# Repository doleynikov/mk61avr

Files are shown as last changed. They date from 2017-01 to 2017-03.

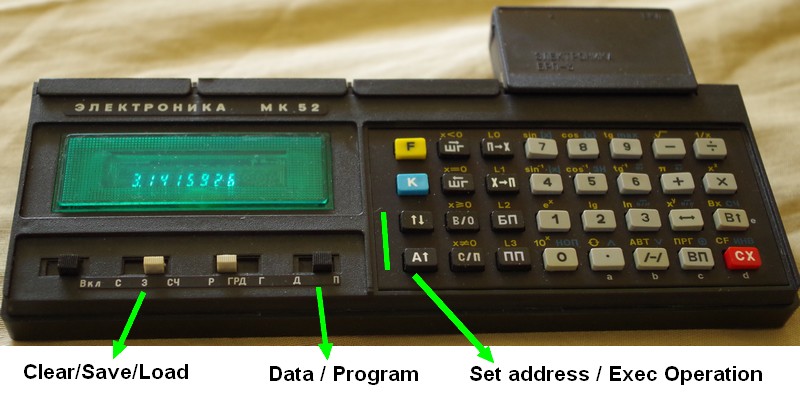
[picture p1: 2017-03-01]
Docs/manual/elek_mk52.jpg

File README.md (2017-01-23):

# mk61avr

**Эмулятор разбросан по файлам**

main.c

mk61types.h

vm61.c

vm61.h

vm61decoder.c

**есть служебные функции**

extlib.c - преобразования 16-ти ричной цифры в символ для печати;

	atoc() - ?;

	чтение-запись участка памяти из/в EEPROM;

**есть работа с аппаратурой**

keyboard.c - работа с клавиатурой как с устройством 

keyboard.h

lcd.c - работа с 16x2 LCD по параллельному интерфейсу

lcd.h

lowlevel.h

micro_os.h

scan_dc.c - преобразование сканкодов клавиатуры в ОПкоды 

store.c - работа с внешним i2c хранилищем

store.h

terminal.c - работа с калькулятором из терминала

terminal.h

time.c - ? работа с таймером. Вероятно для опроса клавиатуры

time.h

twi.c - TWI (i2C) функции для работы с внешним хранилищем

uart.c - библиотека функций для работы с последовательным портом

usart_module.h

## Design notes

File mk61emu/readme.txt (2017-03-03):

/usr/share/arduino/arduino-builder -dump-prefs -logger=machine -hardware /usr/share/arduino/hardware -hardware /home/dimao/.arduino15/packages -tools /usr/share/arduino/tools-builder -tools /usr/share/arduino/hardware/tools/avr -tools /home/dimao/.arduino15/packages -built-in-libraries /usr/share/arduino/libraries -libraries /home/dimao/MySketchbook/libraries -fqbn=arduino:avr:microduino_atmega8o -ide-version=10802 -build-path /home/dimao/MySketchbook/build -warnings=all -prefs=build.warn_data_percentage=75 -prefs=runtime.tools.avrdude.path=/home/dimao/.arduino15/packages/arduino/tools/avrdude/6.3.0-arduino8 -prefs=runtime.tools.arduinoOTA.path=/home/dimao/.arduino15/packages/arduino/tools/arduinoOTA/1.0.0 -prefs=runtime.tools.avr-gcc.path=/home/dimao/.arduino15/packages/arduino/tools/avr-gcc/4.9.2-atmel3.5.3-arduino2 -verbose /home/dimao/git/mk61-avr/mk61emu/mk61emu.ino
/usr/share/arduino/arduino-builder -compile -logger=machine -hardware /usr/share/arduino/hardware -hardware /home/dimao/.arduino15/packages -tools /usr/share/arduino/tools-builder -tools /usr/share/arduino/hardware/tools/avr -tools /home/dimao/.arduino15/packages -built-in-libraries /usr/share/arduino/libraries -libraries /home/dimao/MySketchbook/libraries -fqbn=arduino:avr:microduino_atmega8o -ide-version=10802 -build-path /home/dimao/MySketchbook/build -warnings=all -prefs=build.warn_data_percentage=75 -prefs=runtime.tools.avrdude.path=/home/dimao/.arduino15/packages/arduino/tools/avrdude/6.3.0-arduino8 -prefs=runtime.tools.arduinoOTA.path=/home/dimao/.arduino15/packages/arduino/tools/arduinoOTA/1.0.0 -prefs=runtime.tools.avr-gcc.path=/home/dimao/.arduino15/packages/arduino/tools/avr-gcc/4.9.2-atmel3.5.3-arduino2 -verbose /home/dimao/git/mk61-avr/mk61emu/mk61emu.ino
Using board 'microduino_atmega8o' from platform in folder: /home/dimao/.arduino15/packages/arduino/hardware/avr/1.6.17
Using core 'arduino' from platform in folder: /home/dimao/.arduino15/packages/arduino/hardware/avr/1.6.17
Warning: Board arduino:avr:a8_1MHz doesn't define a 'build.board' preference. Auto-set to: AVR_A8_1MHZ
Warning: Board arduino:avr:microduino_atmega8o doesn't define a 'build.board' preference. Auto-set to: AVR_MICRODUINO_ATMEGA8O
Warning: Board arduino:avr:a8_8MHz doesn't define a 'build.board' preference. Auto-set to: AVR_A8_8MHZ
Warning: Board arduino:avr:atmega8o doesn't define a 'build.board' preference. Auto-set to: AVR_ATMEGA8O
Warning: Board arduino:avr:a8noboot_8MHz doesn't define a 'build.board' preference. Auto-set to: AVR_A8NOBOOT_8MHZ
Изменены опции сборки, пересобираем все
Detecting libraries used...
"/home/dimao/.arduino15/packages/arduino/tools/avr-gcc/4.9.2-atmel3.5.3-arduino2/bin/avr-g++" -c -g -Os -w -std=gnu++11 -fpermissive -fno-exceptions -ffunction-sections -fdata-sections -fno-threadsafe-statics  -flto -w -x c++ -E -CC -mmcu=atmega8 -DF_CPU=8000000L -DARDUINO=10802 -DARDUINO_AVR_MICRODUINO_ATMEGA8O -DARDUINO_ARCH_AVR   "-I/home/dimao/.arduino15/packages/arduino/hardware/avr/1.6.17/cores/arduino" "-I/home/dimao/.arduino15/packages/arduino/hardware/avr/1.6.17/variants/standard" "/home/dimao/MySketchbook/build/sketch/mk61emu.ino.cpp" -o "/dev/null"
"/home/dimao/.arduino15/packages/arduino/tools/avr-gcc/4.9.2-atmel3.5.3-arduino2/bin/avr-g++" -c -g -Os -w -std=gnu++11 -fpermissive -fno-exceptions -ffunction-sections -fdata-sections -fno-threadsafe-statics  -flto -w -x c++ -E -CC -mmcu=atmega8 -DF_CPU=8000000L -DARDUINO=10802 -DARDUINO_AVR_MICRODUINO_ATMEGA8O -DARDUINO_ARCH_AVR   "-I/home/dimao/.arduino15/packages/arduino/hardware/avr/1.6.17/cores/arduino" "-I/home/dimao/.arduino15/packages/arduino/hardware/avr/1.6.17/variants/standard" "/home/dimao/MySketchbook/build/sketch/stack_ops.cpp" -o "/dev/null"
Generating function prototypes...
"/home/dimao/.arduino15/packages/arduino/tools/avr-gcc/4.9.2-atmel3.5.3-arduino2/bin/avr-g++" -c -g -Os -w -std=gnu++11 -fpermissive -fno-exceptions -ffunction-sections -fdata-sections -fno-threadsafe-statics  -flto -w -x c++ -E -CC -mmcu=atmega8 -DF_CPU=8000000L -DARDUINO=10802 -DARDUINO_AVR_MICRODUINO_ATMEGA8O -DARDUINO_ARCH_AVR   "-I/home/dimao/.arduino15/packages/arduino/hardware/avr/1.6.17/cores/arduino" "-I/home/dimao/.arduino15/packages/arduino/hardware/avr/1.6.17/variants/standard" "/home/dimao/MySketchbook/build/sketch/mk61emu.ino.cpp" -o "/home/dimao/MySketchbook/build/preproc/ctags_target_for_gcc_minus_e.cpp"
"/usr/share/arduino/tools-builder/ctags/5.8-arduino11/ctags" -u --language-force=c++ -f - --c++-kinds=svpf --fields=KSTtzns --line-directives "/home/dimao/MySketchbook/build/preproc/ctags_target_for_gcc_minus_e.cpp"
Компиляция скетча...
"/home/dimao/.arduino15/packages/arduino/tools/avr-gcc/4.9.2-atmel3.5.3-arduino2/bin/avr-g++" -c -g -Os -Wall -Wextra -std=gnu++11 -fpermissive -fno-exceptions -ffunction-sections -fdata-sections -fno-threadsafe-statics -MMD -flto -mmcu=atmega8 -DF_CPU=8000000L -DARDUINO=10802 -DARDUINO_AVR_MICRODUINO_ATMEGA8O -DARDUINO_ARCH_AVR   "-I/home/dimao/.arduino15/packages/arduino/hardware/avr/1.6.17/cores/arduino" "-I/home/dimao/.arduino15/packages/arduino/hardware/avr/1.6.17/variants/standard" "/home/dimao/MySketchbook/build/sketch/mk61emu.ino.cpp" -o "/home/dimao/MySketchbook/build/sketch/mk61emu.ino.cpp.o"
/home/dimao/git/mk61-avr/mk61emu/mk61emu.ino:78:20: warning: initializer-string for array of chars is too long [-fpermissive]
 char screenX[16] = " 0               ";
                    ^
/home/dimao/git/mk61-avr/mk61emu/mk61emu.ino:80:19: warning: initializer-string for array of chars is too long [-fpermissive]
 char digits[12] = "0123456789.-";
                   ^
/home/dimao/git/mk61-avr/mk61emu/mk61emu.ino:94:19: warning: unused parameter 'p' [-Wunused-parameter]
 void sCycle(float p) // круговое движение стека назад
                   ^
/home/dimao/git/mk61-avr/mk61emu/mk61emu.ino: In function 'void kb_scan()':
/home/dimao/git/mk61-avr/mk61emu/mk61emu.ino:211:35: warning: suggest parentheses around '+' inside '<<' [-Wparentheses]
         else if (!(PIND & (1 << j + 2)))
                                   ^
/home/dimao/git/mk61-avr/mk61emu/mk61emu.ino: In function 'void loop()':
/home/dimao/git/mk61-avr/mk61emu/mk61emu.ino:231:23: warning: suggest parentheses around assignment used as truth value [-Wparentheses]
     else if (mode = 2 ) 
                       ^
/home/dimao/git/mk61-avr/mk61emu/mk61emu.ino:235:23: warning: suggest parentheses around assignment used as truth value [-Wparentheses]
     else if (mode = 3 ) 
                       ^
"/home/dimao/.arduino15/packages/arduino/tools/avr-gcc/4.9.2-atmel3.5.3-arduino2/bin/avr-g++" -c -g -Os -Wall -Wextra -std=gnu++11 -fpermissive -fno-exceptions -ffunction-sections -fdata-sections -fno-threadsafe-statics -MMD -flto -mmcu=atmega8 -DF_CPU=8000000L -DARDUINO=10802 -DARDUINO_AVR_MICRODUINO_ATMEGA8O -DARDUINO_ARCH_AVR   "-I/home/dimao/.arduino15/packages/arduino/hardware/avr/1.6.17/cores/arduino" "-I/home/dimao/.arduino15/packages/arduino/hardware/avr/1.6.17/variants/standard" "/home/dimao/MySketchbook/build/sketch/stack_ops.cpp" -o "/home/dimao/MySketchbook/build/sketch/stack_ops.cpp.o"
Compiling libraries...
Compiling core...
"/home/dimao/.arduino15/packages/arduino/tools/avr-gcc/4.9.2-atmel3.5.3-arduino2/bin/avr-gcc" -c -g -x assembler-with-cpp -flto -MMD -mmcu=atmega8 -DF_CPU=8000000L -DARDUINO=10802 -DARDUINO_AVR_MICRODUINO_ATMEGA8O -DARDUINO_ARCH_AVR   "-I/home/dimao/.arduino15/packages/arduino/hardware/avr/1.6.17/cores/arduino" "-I/home/dimao/.arduino15/packages/arduino/hardware/avr/1.6.17/variants/standard" "/home/dimao/.arduino15/packages/arduino/hardware/avr/1.6.17/cores/arduino/wiring_pulse.S" -o "/home/dimao/MySketchbook/build/core/wiring_pulse.S.o"
"/home/dimao/.arduino15/packages/arduino/tools/avr-gcc/4.9.2-atmel3.5.3-arduino2/bin/avr-gcc" -c -g -Os -Wall -Wextra -std=gnu11 -ffunction-sections -fdata-sections -MMD -flto -fno-fat-lto-objects -mmcu=atmega8 -DF_CPU=8000000L -DARDUINO=10802 -DARDUINO_AVR_MICRODUINO_ATMEGA8O -DARDUINO_ARCH_AVR   "-I/home/dimao/.arduino15/packages/arduino/hardware/avr/1.6.17/cores/arduino" "-I/home/dimao/.arduino15/packages/arduino/hardware/avr/1.6.17/variants/standard" "/home/dimao/.arduino15/packages/arduino/hardware/avr/1.6.17/cores/arduino/WInterrupts.c" -o "/home/dimao/MySketchbook/build/core/WInterrupts.c.o"
"/home/dimao/.arduino15/packages/arduino/tools/avr-gcc/4.9.2-atmel3.5.3-arduino2/bin/avr-gcc" -c -g -Os -Wall -Wextra -std=gnu11 -ffunction-sections -fdata-sections -MMD -flto -fno-fat-lto-objects -mmcu=atmega8 -DF_CPU=8000000L -DARDUINO=10802 -DARDUINO_AVR_MICRODUINO_ATMEGA8O -DARDUINO_ARCH_AVR   "-I/home/dimao/.arduino15/packages/arduino/hardware/avr/1.6.17/cores/arduino" "-I/home/dimao/.arduino15/packages/arduino/hardware/avr/1.6.17/variants/standard" "/home/dimao/.arduino15/packages/arduino/hardware/avr/1.6.17/cores/arduino/hooks.c" -o "/home/dimao/MySketchbook/build/core/hooks.c.o"
"/home/dimao/.arduino15/packages/arduino/tools/avr-gcc/4.9.2-atmel3.5.3-arduino2/bin/avr-gcc" -c -g -Os -Wall -Wextra -std=gnu11 -ffunction-sections -fdata-sections -MMD -flto -fno-fat-lto-objects -mmcu=atmega8 -DF_CPU=8000000L -DARDUINO=10802 -DARDUINO_AVR_MICRODUINO_ATMEGA8O -DARDUINO_ARCH_AVR   "-I/home/dimao/.arduino15/packages/arduino/hardware/avr/1.6.17/cores/arduino" "-I/home/dimao/.arduino15/packages/arduino/hardware/avr/1.6.17/variants/standard" "/home/dimao/.arduino15/packages/arduino/hardware/avr/1.6.17/cores/arduino/wiring.c" -o "/home/dimao/MySketchbook/build/core/wiring.c.o"
"/home/dimao/.arduino15/packages/arduino/tools/avr-gcc/4.9.2-atmel3.5.3-arduino2/bin/avr-gcc" -c -g -Os -Wall -Wextra -std=gnu11 -ffunction-sections -fdata-sections -MMD -flto -fno-fat-lto-objects -mmcu=atmega8 -DF_CPU=8000000L -DARDUINO=10802 -DARDUINO_AVR_MICRODUINO_ATMEGA8O -DARDUINO_ARCH_AVR   "-I/home/dimao/.arduino15/packages/arduino/hardware/avr/1.6.17/cores/arduino" "-I/home/dimao/.arduino15/packages/arduino/hardware/avr/1.6.17/variants/standard" "/home/dimao/.arduino15/packages/arduino/hardware/avr/1.6.17/cores/arduino/wiring_analog.c" -o "/home/dimao/MySketchbook/build/core/wiring_analog.c.o"
"/home/dimao/.arduino15/packages/arduino/tools/avr-gcc/4.9.2-atmel3.5.3-arduino2/bin/avr-gcc" -c -g -Os -Wall -Wextra -std=gnu11 -ffunction-sections -fdata-sections -MMD -flto -fno-fat-lto-objects -mmcu=atmega8 -DF_CPU=8000000L -DARDUINO=10802 -DARDUINO_AVR_MICRODUINO_ATMEGA8O -DARDUINO_ARCH_AVR   "-I/home/dimao/.arduino15/packages/arduino/hardware/avr/1.6.17/cores/arduino" "-I/home/dimao/.arduino15/packages/arduino/hardware/avr/1.6.17/variants/standard" "/home/dimao/.arduino15/packages/arduino/hardware/avr/1.6.17/cores/arduino/wiring_digital.c" -o "/home/dimao/MySketchbook/build/core/wiring_digital.c.o"
In file included from /home/dimao/.arduino15/packages/arduino/hardware/avr/1.6.17/cores/arduino/wiring_private.h:31:0,
                 from /home/dimao/.arduino15/packages/arduino/hardware/avr/1.6.17/cores/arduino/wiring_digital.c:26:
/home/dimao/.arduino15/packages/arduino/hardware/avr/1.6.17/cores/arduino/Arduino.h:195:0: warning: "PE" redefined
 #define PE 5
 ^
In file included from /home/dimao/.arduino15/packages/arduino/tools/avr-gcc/4.9.2-atmel3.5.3-arduino2/avr/include/avr/io.h:350:0,
                 from /home/dimao/.arduino15/packages/arduino/hardware/avr/1.6.17/cores/arduino/wiring_private.h:26,
                 from /home/dimao/.arduino15/packages/arduino/hardware/avr/1.6.17/cores/arduino/wiring_digital.c:26:
/home/dimao/.arduino15/packages/arduino/tools/avr-gcc/4.9.2-atmel3.5.3-arduino2/avr/include/avr/iom8.h:534:0: note: this is the location of the previous definition
 #define PE 2

 ^
"/home/dimao/.arduino15/packages/arduino/tools/avr-gcc/4.9.2-atmel3.5.3-arduino2/bin/avr-gcc" -c -g -Os -Wall -Wextra -std=gnu11 -ffunction-sections -fdata-sections -MMD -flto -fno-fat-lto-objects -mmcu=atmega8 -DF_CPU=8000000L -DARDUINO=10802 -DARDUINO_AVR_MICRODUINO_ATMEGA8O -DARDUINO_ARCH_AVR   "-I/home/dimao/.arduino15/packages/arduino/hardware/avr/1.6.17/cores/arduino" "-I/home/dimao/.arduino15/packages/arduino/hardware/avr/1.6.17/variants/standard" "/home/dimao/.arduino15/packages/arduino/hardware/avr/1.6.17/cores/arduino/wiring_pulse.c" -o "/home/dimao/MySketchbook/build/core/wiring_pulse.c.o"
"/home/dimao/.arduino15/packages/arduino/tools/avr-gcc/4.9.2-atmel3.5.3-arduino2/bin/avr-gcc" -c -g -Os -Wall -Wextra -std=gnu11 -ffunction-sections -fdata-sections -MMD -flto -fno-fat-lto-objects -mmcu=atmega8 -DF_CPU=8000000L -DARDUINO=10802 -DARDUINO_AVR_MICRODUINO_ATMEGA8O -DARDUINO_ARCH_AVR   "-I/home/dimao/.arduino15/packages/arduino/hardware/avr/1.6.17/cores/arduino" "-I/home/dimao/.arduino15/packages/arduino/hardware/avr/1.6.17/variants/standard" "/home/dimao/.arduino15/packages/arduino/hardware/avr/1.6.17/cores/arduino/wiring_shift.c" -o "/home/dimao/MySketchbook/build/core/wiring_shift.c.o"
"/home/dimao/.arduino15/packages/arduino/tools/avr-gcc/4.9.2-atmel3.5.3-arduino2/bin/avr-g++" -c -g -Os -Wall -Wextra -std=gnu++11 -fpermissive -fno-exceptions -ffunction-sections -fdata-sections -fno-threadsafe-statics -MMD -flto -mmcu=atmega8 -DF_CPU=8000000L -DARDUINO=10802 -DARDUINO_AVR_MICRODUINO_ATMEGA8O -DARDUINO_ARCH_AVR   "-I/home/dimao/.arduino15/packages/arduino/hardware/avr/1.6.17/cores/arduino" "-I/home/dimao/.arduino15/packages/arduino/hardware/avr/1.6.17/variants/standard" "/home/dimao/.arduino15/packages/arduino/hardware/avr/1.6.17/cores/arduino/CDC.cpp" -o "/home/dimao/MySketchbook/build/core/CDC.cpp.o"
"/home/dimao/.arduino15/packages/arduino/tools/avr-gcc/4.9.2-atmel3.5.3-arduino2/bin/avr-g++" -c -g -Os -Wall -Wextra -std=gnu++11 -fpermissive -fno-exceptions -ffunction-sections -fdata-sections -fno-threadsafe-statics -MMD -flto -mmcu=atmega8 -DF_CPU=8000000L -DARDUINO=10802 -DARDUINO_AVR_MICRODUINO_ATMEGA8O -DARDUINO_ARCH_AVR   "-I/home/dimao/.arduino15/packages/arduino/hardware/avr/1.6.17/cores/arduino" "-I/home/dimao/.arduino15/packages/arduino/hardware/avr/1.6.17/variants/standard" "/home/dimao/.arduino15/packages/arduino/hardware/avr/1.6.17/cores/arduino/HardwareSerial.cpp" -o "/home/dimao/MySketchbook/build/core/HardwareSerial.cpp.o"
"/home/dimao/.arduino15/packages/arduino/tools/avr-gcc/4.9.2-atmel3.5.3-arduino2/bin/avr-g++" -c -g -Os -Wall -Wextra -std=gnu++11 -fpermissive -fno-exceptions -ffunction-sections -fdata-sections -fno-threadsafe-statics -MMD -flto -mmcu=atmega8 -DF_CPU=8000000L -DARDUINO=10802 -DARDUINO_AVR_MICRODUINO_ATMEGA8O -DARDUINO_ARCH_AVR   "-I/home/dimao/.arduino15/packages/arduino/hardware/avr/1.6.17/cores/arduino" "-I/home/dimao/.arduino15/packages/arduino/hardware/avr/1.6.17/variants/standard" "/home/dimao/.arduino15/packages/arduino/hardware/avr/1.6.17/cores/arduino/HardwareSerial0.cpp" -o "/home/dimao/MySketchbook/build/core/HardwareSerial0.cpp.o"
"/home/dimao/.arduino15/packages/arduino/tools/avr-gcc/4.9.2-atmel3.5.3-arduino2/bin/avr-g++" -c -g -Os -Wall -Wextra -std=gnu++11 -fpermissive -fno-exceptions -ffunction-sections -fdata-sections -fno-threadsafe-statics -MMD -flto -mmcu=atmega8 -DF_CPU=8000000L -DARDUINO=10802 -DARDUINO_AVR_MICRODUINO_ATMEGA8O -DARDUINO_ARCH_AVR   "-I/home/dimao/.arduino15/packages/arduino/hardware/avr/1.6.17/cores/arduino" "-I/home/dimao/.arduino15/packages/arduino/hardware/avr/1.6.17/variants/standard" "/home/dimao/.arduino15/packages/arduino/hardware/avr/1.6.17/cores/arduino/HardwareSerial1.cpp" -o "/home/dimao/MySketchbook/build/core/HardwareSerial1.cpp.o"
"/home/dimao/.arduino15/packages/arduino/tools/avr-gcc/4.9.2-atmel3.5.3-arduino2/bin/avr-g++" -c -g -Os -Wall -Wextra -std=gnu++11 -fpermissive -fno-exceptions -ffunction-sections -fdata-sections -fno-threadsafe-statics -MMD -flto -mmcu=atmega8 -DF_CPU=8000000L -DARDUINO=10802 -DARDUINO_AVR_MICRODUINO_ATMEGA8O -DARDUINO_ARCH_AVR   "-I/home/dimao/.arduino15/packages/arduino/hardware/avr/1.6.17/cores/arduino" "-I/home/dimao/.arduino15/packages/arduino/hardware/avr/1.6.17/variants/standard" "/home/dimao/.arduino15/packages/arduino/hardware/avr/1.6.17/cores/arduino/HardwareSerial2.cpp" -o "/home/dimao/MySketchbook/build/core/HardwareSerial2.cpp.o"
"/home/dimao/.arduino15/packages/arduino/tools/avr-gcc/4.9.2-atmel3.5.3-arduino2/bin/avr-g++" -c -g -Os -Wall -Wextra -std=gnu++11 -fpermissive -fno-exceptions -ffunction-sections -fdata-sections -fno-threadsafe-statics -MMD -flto -mmcu=atmega8 -DF_CPU=8000000L -DARDUINO=10802 -DARDUINO_AVR_MICRODUINO_ATMEGA8O -DARDUINO_ARCH_AVR   "-I/home/dimao/.arduino15/packages/arduino/hardware/avr/1.6.17/cores/arduino" "-I/home/dimao/.arduino15/packages/arduino/hardware/avr/1.6.17/variants/standard" "/home/dimao/.arduino15/packages/arduino/hardware/avr/1.6.17/cores/arduino/HardwareSerial3.cpp" -o "/home/dimao/MySketchbook/build/core/HardwareSerial3.cpp.o"
"/home/dimao/.arduino15/packages/arduino/tools/avr-gcc/4.9.2-atmel3.5.3-arduino2/bin/avr-g++" -c -g -Os -Wall -Wextra -std=gnu++11 -fpermissive -fno-exceptions -ffunction-sections -fdata-sections -fno-threadsafe-statics -MMD -flto -mmcu=atmega8 -DF_CPU=8000000L -DARDUINO=10802 -DARDUINO_AVR_MICRODUINO_ATMEGA8O -DARDUINO_ARCH_AVR   "-I/home/dimao/.arduino15/packages/arduino/hardware/avr/1.6.17/cores/arduino" "-I/home/dimao/.arduino15/packages/arduino/hardware/avr/1.6.17/variants/standard" "/home/dimao/.arduino15/packages/arduino/hardware/avr/1.6.17/cores/arduino/IPAddress.cpp" -o "/home/dimao/MySketchbook/build/core/IPAddress.cpp.o"
"/home/dimao/.arduino15/packages/arduino/tools/avr-gcc/4.9.2-atmel3.5.3-arduino2/bin/avr-g++" -c -g -Os -Wall -Wextra -std=gnu++11 -fpermissive -fno-exceptions -ffunction-sections -fdata-sections -fno-threadsafe-statics -MMD -flto -mmcu=atmega8 -DF_CPU=8000000L -DARDUINO=10802 -DARDUINO_AVR_MICRODUINO_ATMEGA8O -DARDUINO_ARCH_AVR   "-I/home/dimao/.arduino15/packages/arduino/hardware/avr/1.6.17/cores/arduino" "-I/home/dimao/.arduino15/packages/arduino/hardware/avr/1.6.17/variants/standard" "/home/dimao/.arduino15/packages/arduino/hardware/avr/1.6.17/cores/arduino/PluggableUSB.cpp" -o "/home/dimao/MySketchbook/build/core/PluggableUSB.cpp.o"
"/home/dimao/.arduino15/packages/arduino/tools/avr-gcc/4.9.2-atmel3.5.3-arduino2/bin/avr-g++" -c -g -Os -Wall -Wextra -std=gnu++11 -fpermissive -fno-exceptions -ffunction-sections -fdata-sections -fno-threadsafe-statics -MMD -flto -mmcu=atmega8 -DF_CPU=8000000L -DARDUINO=10802 -DARDUINO_AVR_MICRODUINO_ATMEGA8O -DARDUINO_ARCH_AVR   "-I/home/dimao/.arduino15/packages/arduino/hardware/avr/1.6.17/cores/arduino" "-I/home/dimao/.arduino15/packages/arduino/hardware/avr/1.6.17/variants/standard" "/home/dimao/.arduino15/packages/arduino/hardware/avr/1.6.17/cores/arduino/Print.cpp" -o "/home/dimao/MySketchbook/build/core/Print.cpp.o"
"/home/dimao/.arduino15/packages/arduino/tools/avr-gcc/4.9.2-atmel3.5.3-arduino2/bin/avr-g++" -c -g -Os -Wall -Wextra -std=gnu++11 -fpermissive -fno-exceptions -ffunction-sections -fdata-sections -fno-threadsafe-statics -MMD -flto -mmcu=atmega8 -DF_CPU=8000000L -DARDUINO=10802 -DARDUINO_AVR_MICRODUINO_ATMEGA8O -DARDUINO_ARCH_AVR   "-I/home/dimao/.arduino15/packages/arduino/hardware/avr/1.6.17/cores/arduino" "-I/home/dimao/.arduino15/packages/arduino/hardware/avr/1.6.17/variants/standard" "/home/dimao/.arduino15/packages/arduino/hardware/avr/1.6.17/cores/arduino/Stream.cpp" -o "/home/dimao/MySketchbook/build/core/Stream.cpp.o"
"/home/dimao/.arduino15/packages/arduino/tools/avr-gcc/4.9.2-atmel3.5.3-arduino2/bin/avr-g++" -c -g -Os -Wall -Wextra -std=gnu++11 -fpermissive -fno-exceptions -ffunction-sections -fdata-sections -fno-threadsafe-statics -MMD -flto -mmcu=atmega8 -DF_CPU=8000000L -DARDUINO=10802 -DARDUINO_AVR_MICRODUINO_ATMEGA8O -DARDUINO_ARCH_AVR   "-I/home/dimao/.arduino15/packages/arduino/hardware/avr/1.6.17/cores/arduino" "-I/home/dimao/.arduino15/packages/arduino/hardware/avr/1.6.17/variants/standard" "/home/dimao/.arduino15/packages/arduino/hardware/avr/1.6.17/cores/arduino/Tone.cpp" -o "/home/dimao/MySketchbook/build/core/Tone.cpp.o"
"/home/dimao/.arduino15/packages/arduino/tools/avr-gcc/4.9.2-atmel3.5.3-arduino2/bin/avr-g++" -c -g -Os -Wall -Wextra -std=gnu++11 -fpermissive -fno-exceptions -ffunction-sections -fdata-sections -fno-threadsafe-statics -MMD -flto -mmcu=atmega8 -DF_CPU=8000000L -DARDUINO=10802 -DARDUINO_AVR_MICRODUINO_ATMEGA8O -DARDUINO_ARCH_AVR   "-I/home/dimao/.arduino15/packages/arduino/hardware/avr/1.6.17/cores/arduino" "-I/home/dimao/.arduino15/packages/arduino/hardware/avr/1.6.17/variants/standard" "/home/dimao/.arduino15/packages/arduino/hardware/avr/1.6.17/cores/arduino/USBCore.cpp" -o "/home/dimao/MySketchbook/build/core/USBCore.cpp.o"
"/home/dimao/.arduino15/packages/arduino/tools/avr-gcc/4.9.2-atmel3.5.3-arduino2/bin/avr-g++" -c -g -Os -Wall -Wextra -std=gnu++11 -fpermissive -fno-exceptions -ffunction-sections -fdata-sections -fno-threadsafe-statics -MMD -flto -mmcu=atmega8 -DF_CPU=8000000L -DARDUINO=10802 -DARDUINO_AVR_MICRODUINO_ATMEGA8O -DARDUINO_ARCH_AVR   "-I/home/dimao/.arduino15/packages/arduino/hardware/avr/1.6.17/cores/arduino" "-I/home/dimao/.arduino15/packages/arduino/hardware/avr/1.6.17/variants/standard" "/home/dimao/.arduino15/packages/arduino/hardware/avr/1.6.17/cores/arduino/WMath.cpp" -o "/home/dimao/MySketchbook/build/core/WMath.cpp.o"
"/home/dimao/.arduino15/packages/arduino/tools/avr-gcc/4.9.2-atmel3.5.3-arduino2/bin/avr-g++" -c -g -Os -Wall -Wextra -std=gnu++11 -fpermissive -fno-exceptions -ffunction-sections -fdata-sections -fno-threadsafe-statics -MMD -flto -mmcu=atmega8 -DF_CPU=8000000L -DARDUINO=10802 -DARDUINO_AVR_MICRODUINO_ATMEGA8O -DARDUINO_ARCH_AVR   "-I/home/dimao/.arduino15/packages/arduino/hardware/avr/1.6.17/cores/arduino" "-I/home/dimao/.arduino15/packages/arduino/hardware/avr/1.6.17/variants/standard" "/home/dimao/.arduino15/packages/arduino/hardware/avr/1.6.17/cores/arduino/WString.cpp" -o "/home/dimao/MySketchbook/build/core/WString.cpp.o"
"/home/dimao/.arduino15/packages/arduino/tools/avr-gcc/4.9.2-atmel3.5.3-arduino2/bin/avr-g++" -c -g -Os -Wall -Wextra -std=gnu++11 -fpermissive -fno-exceptions -ffunction-sections -fdata-sections -fno-threadsafe-statics -MMD -flto -mmcu=atmega8 -DF_CPU=8000000L -DARDUINO=10802 -DARDUINO_AVR_MICRODUINO_ATMEGA8O -DARDUINO_ARCH_AVR   "-I/home/dimao/.arduino15/packages/arduino/hardware/avr/1.6.17/cores/arduino" "-I/home/dimao/.arduino15/packages/arduino/hardware/avr/1.6.17/variants/standard" "/home/dimao/.arduino15/packages/arduino/hardware/avr/1.6.17/cores/arduino/abi.cpp" -o "/home/dimao/MySketchbook/build/core/abi.cpp.o"
"/home/dimao/.arduino15/packages/arduino/tools/avr-gcc/4.9.2-atmel3.5.3-arduino2/bin/avr-g++" -c -g -Os -Wall -Wextra -std=gnu++11 -fpermissive -fno-exceptions -ffunction-sections -fdata-sections -fno-threadsafe-statics -MMD -flto -mmcu=atmega8 -DF_CPU=8000000L -DARDUINO=10802 -DARDUINO_AVR_MICRODUINO_ATMEGA8O -DARDUINO_ARCH_AVR   "-I/home/dimao/.arduino15/packages/arduino/hardware/avr/1.6.17/cores/arduino" "-I/home/dimao/.arduino15/packages/arduino/hardware/avr/1.6.17/variants/standard" "/home/dimao/.arduino15/packages/arduino/hardware/avr/1.6.17/cores/arduino/main.cpp" -o "/home/dimao/MySketchbook/build/core/main.cpp.o"
"/home/dimao/.arduino15/packages/arduino/tools/avr-gcc/4.9.2-atmel3.5.3-arduino2/bin/avr-g++" -c -g -Os -Wall -Wextra -std=gnu++11 -fpermissive -fno-exceptions -ffunction-sections -fdata-sections -fno-threadsafe-statics -MMD -flto -mmcu=atmega8 -DF_CPU=8000000L -DARDUINO=10802 -DARDUINO_AVR_MICRODUINO_ATMEGA8O -DARDUINO_ARCH_AVR   "-I/home/dimao/.arduino15/packages/arduino/hardware/avr/1.6.17/cores/arduino" "-I/home/dimao/.arduino15/packages/arduino/hardware/avr/1.6.17/variants/standard" "/home/dimao/.arduino15/packages/arduino/hardware/avr/1.6.17/cores/arduino/new.cpp" -o "/home/dimao/MySketchbook/build/core/new.cpp.o"
"/home/dimao/.arduino15/packages/arduino/tools/avr-gcc/4.9.2-atmel3.5.3-arduino2/bin/avr-gcc-ar" rcs  "/home/dimao/MySketchbook/build/core/core.a" "/home/dimao/MySketchbook/build/core/wiring_pulse.S.o"
"/home/dimao/.arduino15/packages/arduino/tools/avr-gcc/4.9.2-atmel3.5.3-arduino2/bin/avr-gcc-ar" rcs  "/home/dimao/MySketchbook/build/core/core.a" "/home/dimao/MySketchbook/build/core/WInterrupts.c.o"
"/home/dimao/.arduino15/packages/arduino/tools/avr-gcc/4.9.2-atmel3.5.3-arduino2/bin/avr-gcc-ar" rcs  "/home/dimao/MySketchbook/build/core/core.a" "/home/dimao/MySketchbook/build/core/hooks.c.o"
"/home/dimao/.arduino15/packages/arduino/tools/avr-gcc/4.9.2-atmel3.5.3-arduino2/bin/avr-gcc-ar" rcs  "/home/dimao/MySketchbook/build/core/core.a" "/home/dimao/MySketchbook/build/core/wiring.c.o"
"/home/dimao/.arduino15/packages/arduino/tools/avr-gcc/4.9.2-atmel3.5.3-arduino2/bin/avr-gcc-ar" rcs  "/home/dimao/MySketchbook/build/core/core.a" "/home/dimao/MySketchbook/build/core/wiring_analog.c.o"
"/home/dimao/.arduino15/packages/arduino/tools/avr-gcc/4.9.2-atmel3.5.3-arduino2/bin/avr-gcc-ar" rcs  "/home/dimao/MySketchbook/build/core/core.a" "/home/dimao/MySketchbook/build/core/wiring_digital.c.o"
"/home/dimao/.arduino15/packages/arduino/tools/avr-gcc/4.9.2-atmel3.5.3-arduino2/bin/avr-gcc-ar" rcs  "/home/dimao/MySketchbook/build/core/core.a" "/home/dimao/MySketchbook/build/core/wiring_pulse.c.o"
"/home/dimao/.arduino15/packages/arduino/tools/avr-gcc/4.9.2-atmel3.5.3-arduino2/bin/avr-gcc-ar" rcs  "/home/dimao/MySketchbook/build/core/core.a" "/home/dimao/MySketchbook/build/core/wiring_shift.c.o"
"/home/dimao/.arduino15/packages/arduino/tools/avr-gcc/4.9.2-atmel3.5.3-arduino2/bin/avr-gcc-ar" rcs  "/home/dimao/MySketchbook/build/core/core.a" "/home/dimao/MySketchbook/build/core/CDC.cpp.o"
"/home/dimao/.arduino15/packages/arduino/tools/avr-gcc/4.9.2-atmel3.5.3-arduino2/bin/avr-gcc-ar" rcs  "/home/dimao/MySketchbook/build/core/core.a" "/home/dimao/MySketchbook/build/core/HardwareSerial.cpp.o"
"/home/dimao/.arduino15/packages/arduino/tools/avr-gcc/4.9.2-atmel3.5.3-arduino2/bin/avr-gcc-ar" rcs  "/home/dimao/MySketchbook/build/core/core.a" "/home/dimao/MySketchbook/build/core/HardwareSerial0.cpp.o"
"/home/dimao/.arduino15/packages/arduino/tools/avr-gcc/4.9.2-atmel3.5.3-arduino2/bin/avr-gcc-ar" rcs  "/home/dimao/MySketchbook/build/core/core.a" "/home/dimao/MySketchbook/build/core/HardwareSerial1.cpp.o"
"/home/dimao/.arduino15/packages/arduino/tools/avr-gcc/4.9.2-atmel3.5.3-arduino2/bin/avr-gcc-ar" rcs  "/home/dimao/MySketchbook/build/core/core.a" "/home/dimao/MySketchbook/build/core/HardwareSerial2.cpp.o"
"/home/dimao/.arduino15/packages/arduino/tools/avr-gcc/4.9.2-atmel3.5.3-arduino2/bin/avr-gcc-ar" rcs  "/home/dimao/MySketchbook/build/core/core.a" "/home/dimao/MySketchbook/build/core/HardwareSerial3.cpp.o"
"/home/dimao/.arduino15/packages/arduino/tools/avr-gcc/4.9.2-atmel3.5.3-arduino2/bin/avr-gcc-ar" rcs  "/home/dimao/MySketchbook/build/core/core.a" "/home/dimao/MySketchbook/build/core/IPAddress.cpp.o"
"/home/dimao/.arduino15/packages/arduino/tools/avr-gcc/4.9.2-atmel3.5.3-arduino2/bin/avr-gcc-ar" rcs  "/home/dimao/MySketchbook/build/core/core.a" "/home/dimao/MySketchbook/build/core/PluggableUSB.cpp.o"
"/home/dimao/.arduino15/packages/arduino/tools/avr-gcc/4.9.2-atmel3.5.3-arduino2/bin/avr-gcc-ar" rcs  "/home/dimao/MySketchbook/build/core/core.a" "/home/dimao/MySketchbook/build/core/Print.cpp.o"
"/home/dimao/.arduino15/packages/arduino/tools/avr-gcc/4.9.2-atmel3.5.3-arduino2/bin/avr-gcc-ar" rcs  "/home/dimao/MySketchbook/build/core/core.a" "/home/dimao/MySketchbook/build/core/Stream.cpp.o"
"/home/dimao/.arduino15/packages/arduino/tools/avr-gcc/4.9.2-atmel3.5.3-arduino2/bin/avr-gcc-ar" rcs  "/home/dimao/MySketchbook/build/core/core.a" "/home/dimao/MySketchbook/build/core/Tone.cpp.o"
"/home/dimao/.arduino15/packages/arduino/tools/avr-gcc/4.9.2-atmel3.5.3-arduino2/bin/avr-gcc-ar" rcs  "/home/dimao/MySketchbook/build/core/core.a" "/home/dimao/MySketchbook/build/core/USBCore.cpp.o"
"/home/dimao/.arduino15/packages/arduino/tools/avr-gcc/4.9.2-atmel3.5.3-arduino2/bin/avr-gcc-ar" rcs  "/home/dimao/MySketchbook/build/core/core.a" "/home/dimao/MySketchbook/build/core/WMath.cpp.o"
"/home/dimao/.arduino15/packages/arduino/tools/avr-gcc/4.9.2-atmel3.5.3-arduino2/bin/avr-gcc-ar" rcs  "/home/dimao/MySketchbook/build/core/core.a" "/home/dimao/MySketchbook/build/core/WString.cpp.o"
"/home/dimao/.arduino15/packages/arduino/tools/avr-gcc/4.9.2-atmel3.5.3-arduino2/bin/avr-gcc-ar" rcs  "/home/dimao/MySketchbook/build/core/core.a" "/home/dimao/MySketchbook/build/core/abi.cpp.o"
"/home/dimao/.arduino15/packages/arduino/tools/avr-gcc/4.9.2-atmel3.5.3-arduino2/bin/avr-gcc-ar" rcs  "/home/dimao/MySketchbook/build/core/core.a" "/home/dimao/MySketchbook/build/core/main.cpp.o"
"/home/dimao/.arduino15/packages/arduino/tools/avr-gcc/4.9.2-atmel3.5.3-arduino2/bin/avr-gcc-ar" rcs  "/home/dimao/MySketchbook/build/core/core.a" "/home/dimao/MySketchbook/build/core/new.cpp.o"
Linking everything together...
"/home/dimao/.arduino15/packages/arduino/tools/avr-gcc/4.9.2-atmel3.5.3-arduino2/bin/avr-gcc" -Wall -Wextra -Os -g -flto -fuse-linker-plugin -Wl,--gc-sections -mmcu=atmega8  -o "/home/dimao/MySketchbook/build/mk61emu.ino.elf" "/home/dimao/MySketchbook/build/sketch/mk61emu.ino.cpp.o" "/home/dimao/MySketchbook/build/sketch/stack_ops.cpp.o" "/home/dimao/MySketchbook/build/core/core.a" "-L/home/dimao/MySketchbook/build" -lm
"/home/dimao/.arduino15/packages/arduino/tools/avr-gcc/4.9.2-atmel3.5.3-arduino2/bin/avr-objcopy" -O ihex -j .eeprom --set-section-flags=.eeprom=alloc,load --no-change-warnings --change-section-lma .eeprom=0  "/home/dimao/MySketchbook/build/mk61emu.ino.elf" "/home/dimao/MySketchbook/build/mk61emu.ino.eep"
"/home/dimao/.arduino15/packages/arduino/tools/avr-gcc/4.9.2-atmel3.5.3-arduino2/bin/avr-objcopy" -O ihex -R .eeprom  "/home/dimao/MySketchbook/build/mk61emu.ino.elf" "/home/dimao/MySketchbook/build/mk61emu.ino.hex"
Скетч использует 7472 байт (97%) памяти устройства. Всего доступно 7680 байт.
Глобальные переменные используют 437 байт динамической памяти.
/home/dimao/.arduino15/packages/arduino/tools/avrdude/6.3.0-arduino8/bin/avrdude -C/home/dimao/.arduino15/packages/arduino/tools/avrdude/6.3.0-arduino8/etc/avrdude.conf -v -patmega8 -cusbasp -Pusb -Uflash:w:/home/dimao/MySketchbook/build/mk61emu.ino.hex:i

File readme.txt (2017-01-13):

*****************************************************************
*                                                               *
*  Форматирование исходных текстов (MK61AVR Coding convention)  *
*                                                               *
*****************************************************************

1. Вместо символов табуляции используется "пробел"

2. Отступ в функциях 4 пробела:

    void About(void)
    {
        int i = 0;
    ^^^^

3. Открывающие и закрывающие скобки на отдельных строках:

    if (i = 0)
    {
        ...

    }

4. Условные операторы и т.п. всегда имеют парные скобки:

    if (i > 200)
    {
    i = 0;
    }

5. Формат условных операторов:

    if (rs)
    {

    }
    else
    {

    }

6....

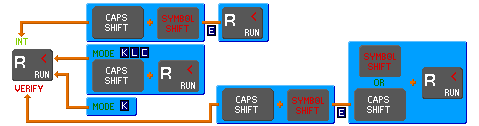
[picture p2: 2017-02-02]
hwTest/mmm/zx-spectrum_keyboard-diagram.gif

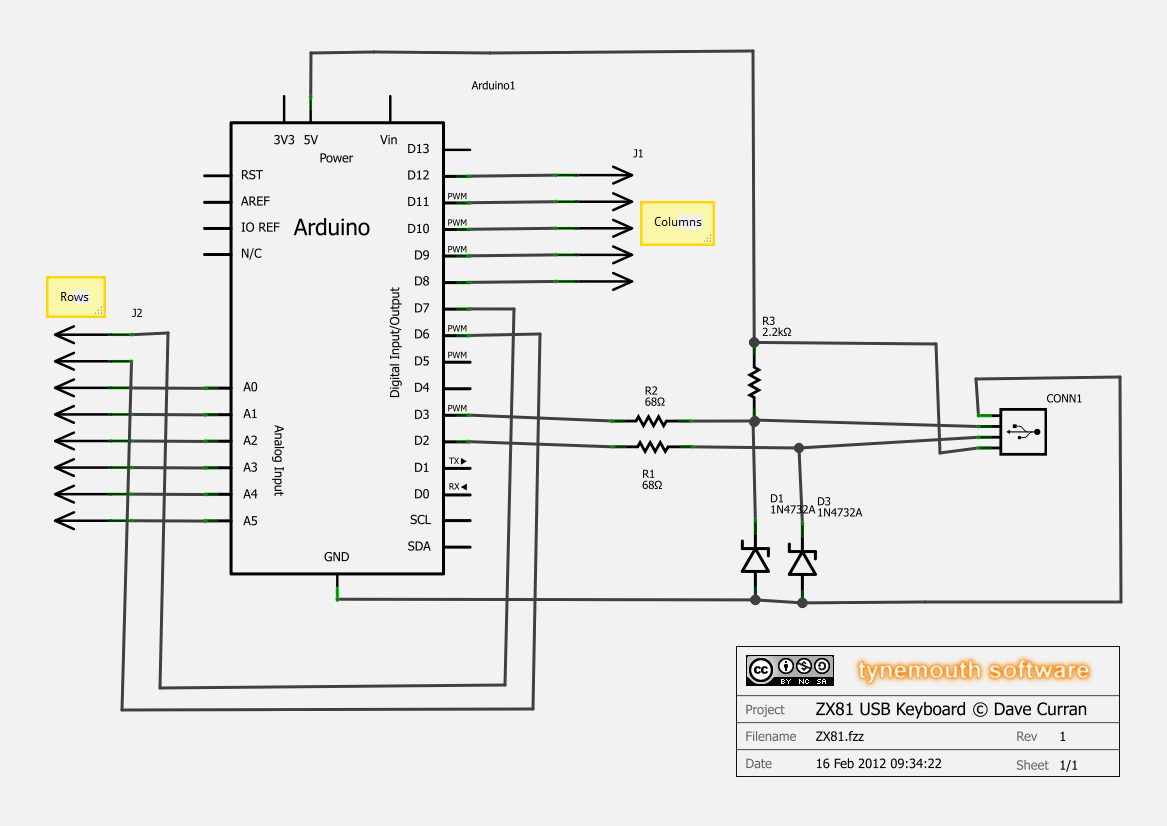
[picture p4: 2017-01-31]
hwTest/mmm/ZX81 USB Schematic.png

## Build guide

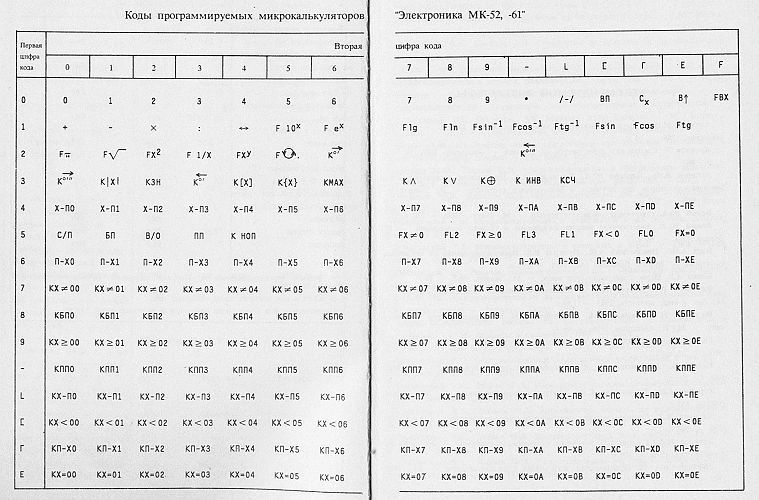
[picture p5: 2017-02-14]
Docs/manual/4fbd872f.jpg

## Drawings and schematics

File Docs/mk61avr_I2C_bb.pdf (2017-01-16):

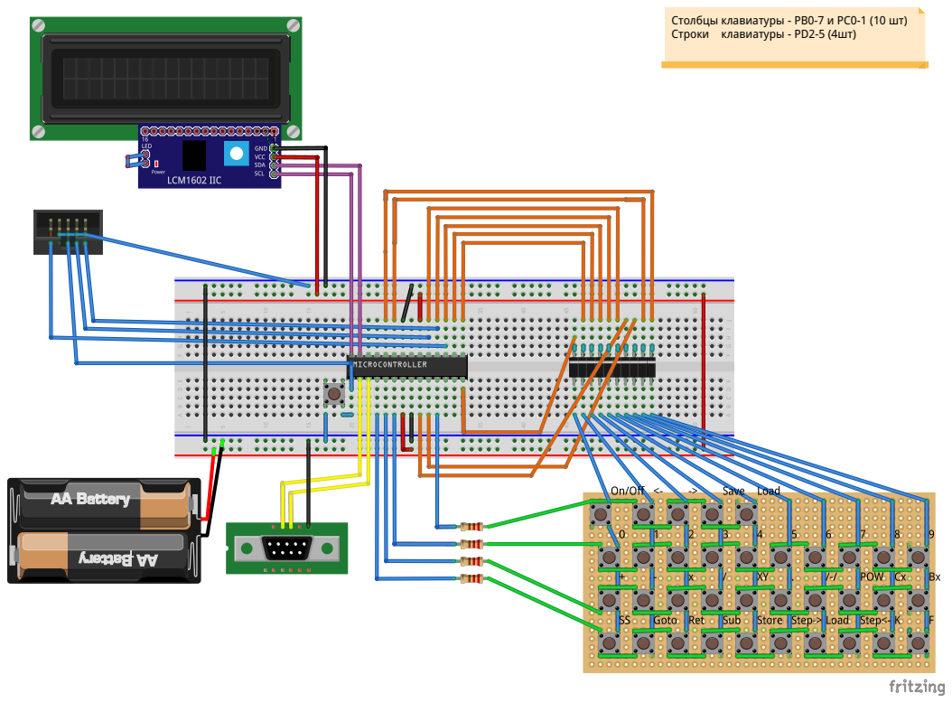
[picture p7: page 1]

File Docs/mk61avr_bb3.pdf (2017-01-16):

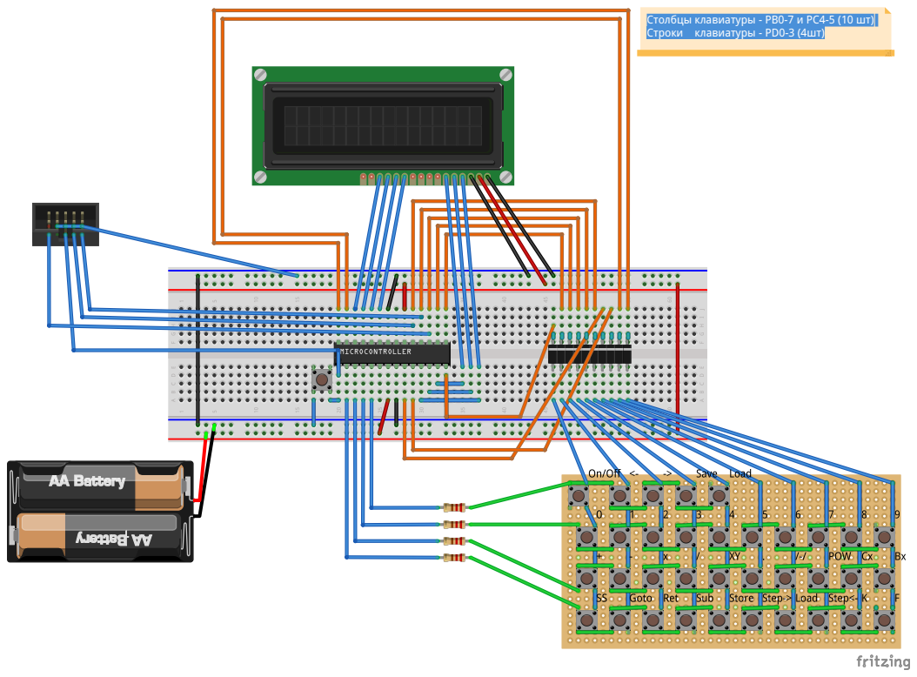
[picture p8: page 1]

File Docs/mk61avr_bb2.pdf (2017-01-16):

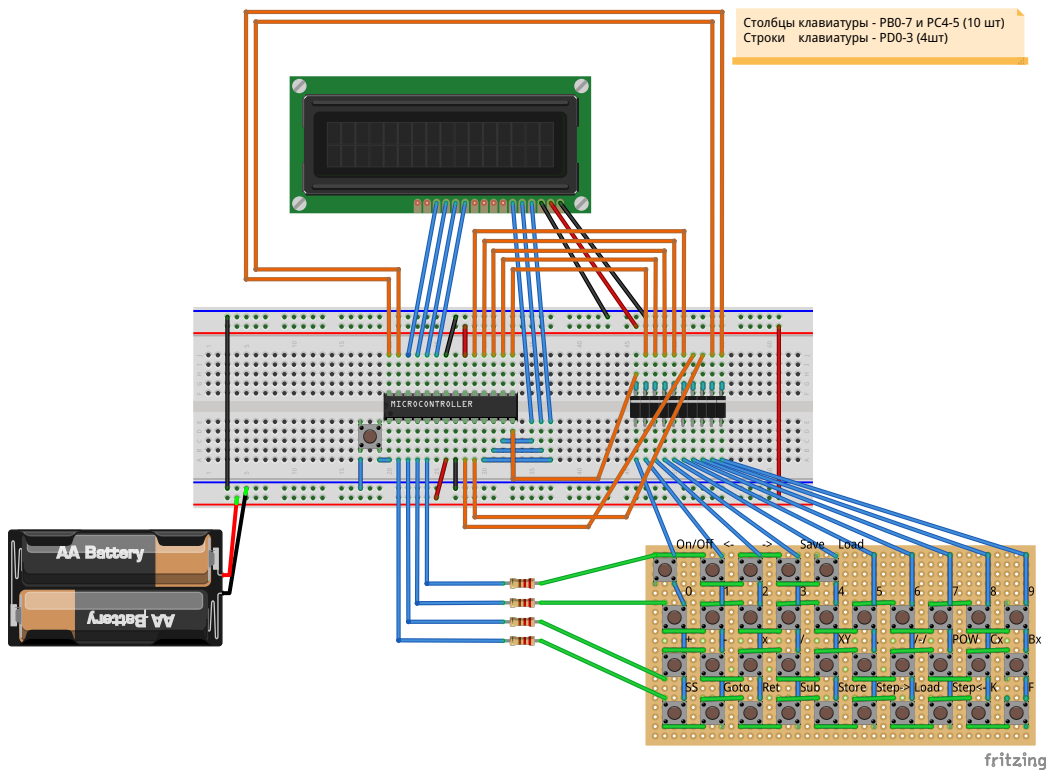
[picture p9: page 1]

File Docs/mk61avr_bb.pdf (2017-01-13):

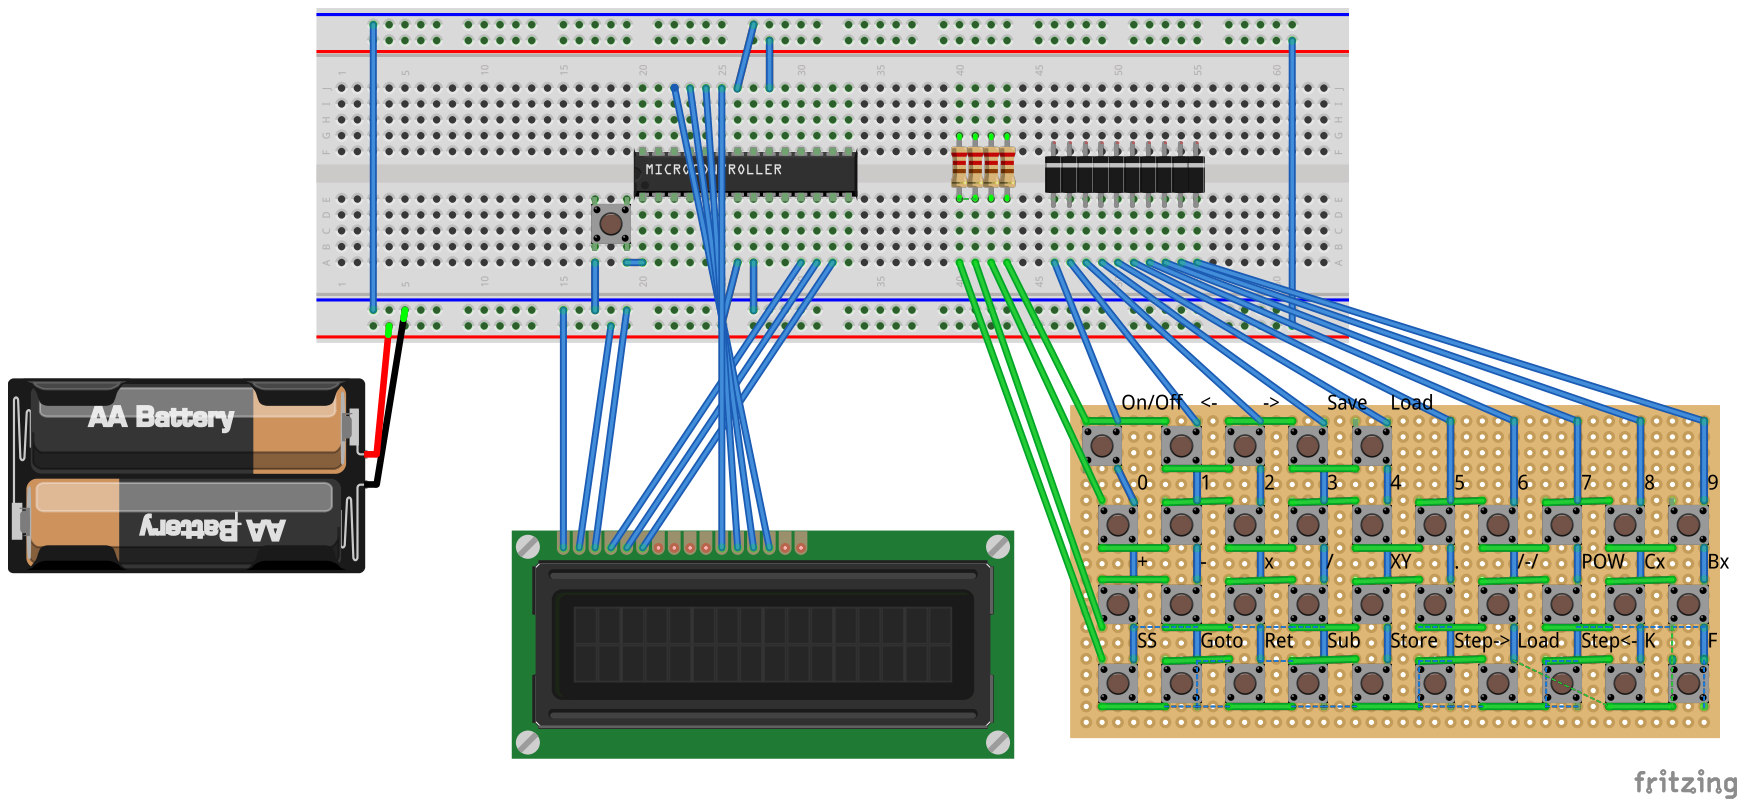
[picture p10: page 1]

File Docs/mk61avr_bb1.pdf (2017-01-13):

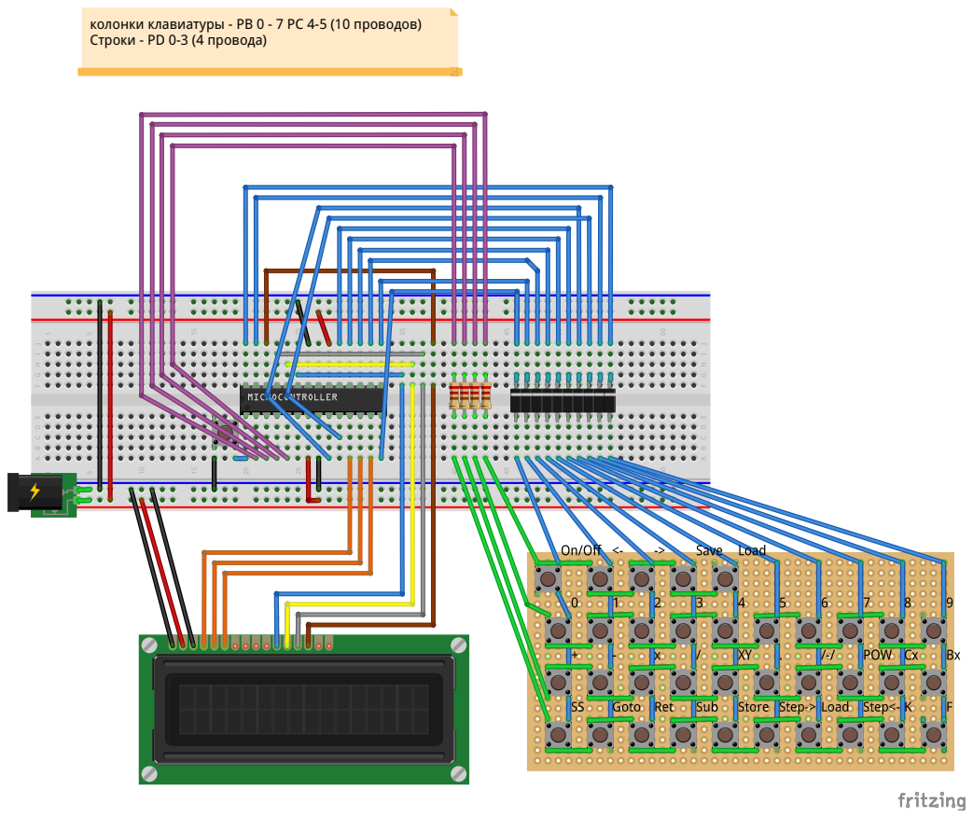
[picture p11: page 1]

колонки клавиатуры - PB 0 - 7 PC 4-5 (10 проводов)
Строки - PD 0-3 (4 провода)

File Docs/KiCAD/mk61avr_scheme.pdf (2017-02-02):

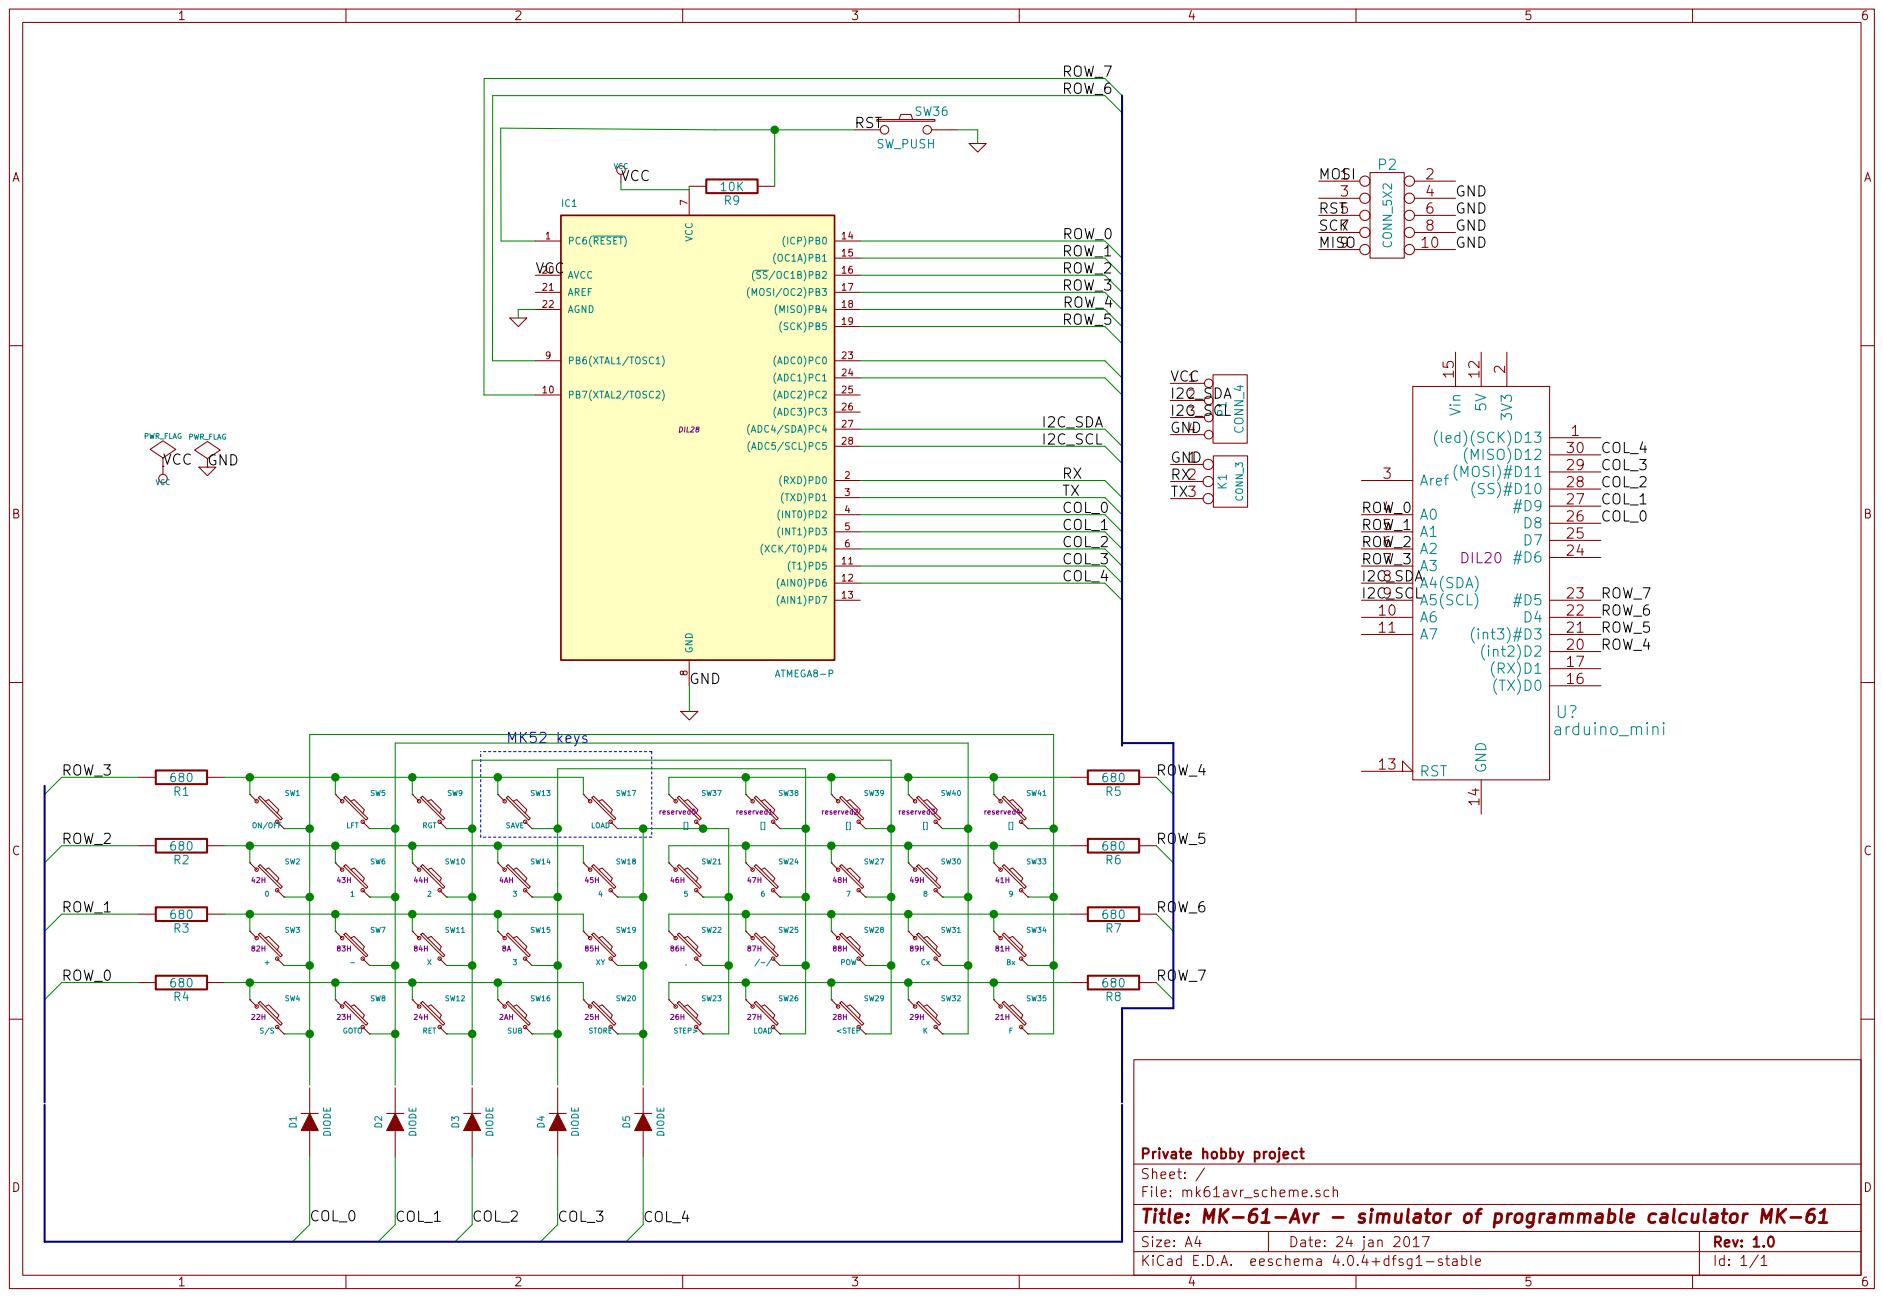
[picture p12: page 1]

680 | SW9 RGT SW5 | SW13 SAVE | LOAD | [] reserved2 | [] reserved3 SW40 | SW41

File: mk61avr_scheme.sch Sheet: / Private hobby project

Id: 1/1 Title: MK-61-Avr - simulator of programmable calculator MK-61

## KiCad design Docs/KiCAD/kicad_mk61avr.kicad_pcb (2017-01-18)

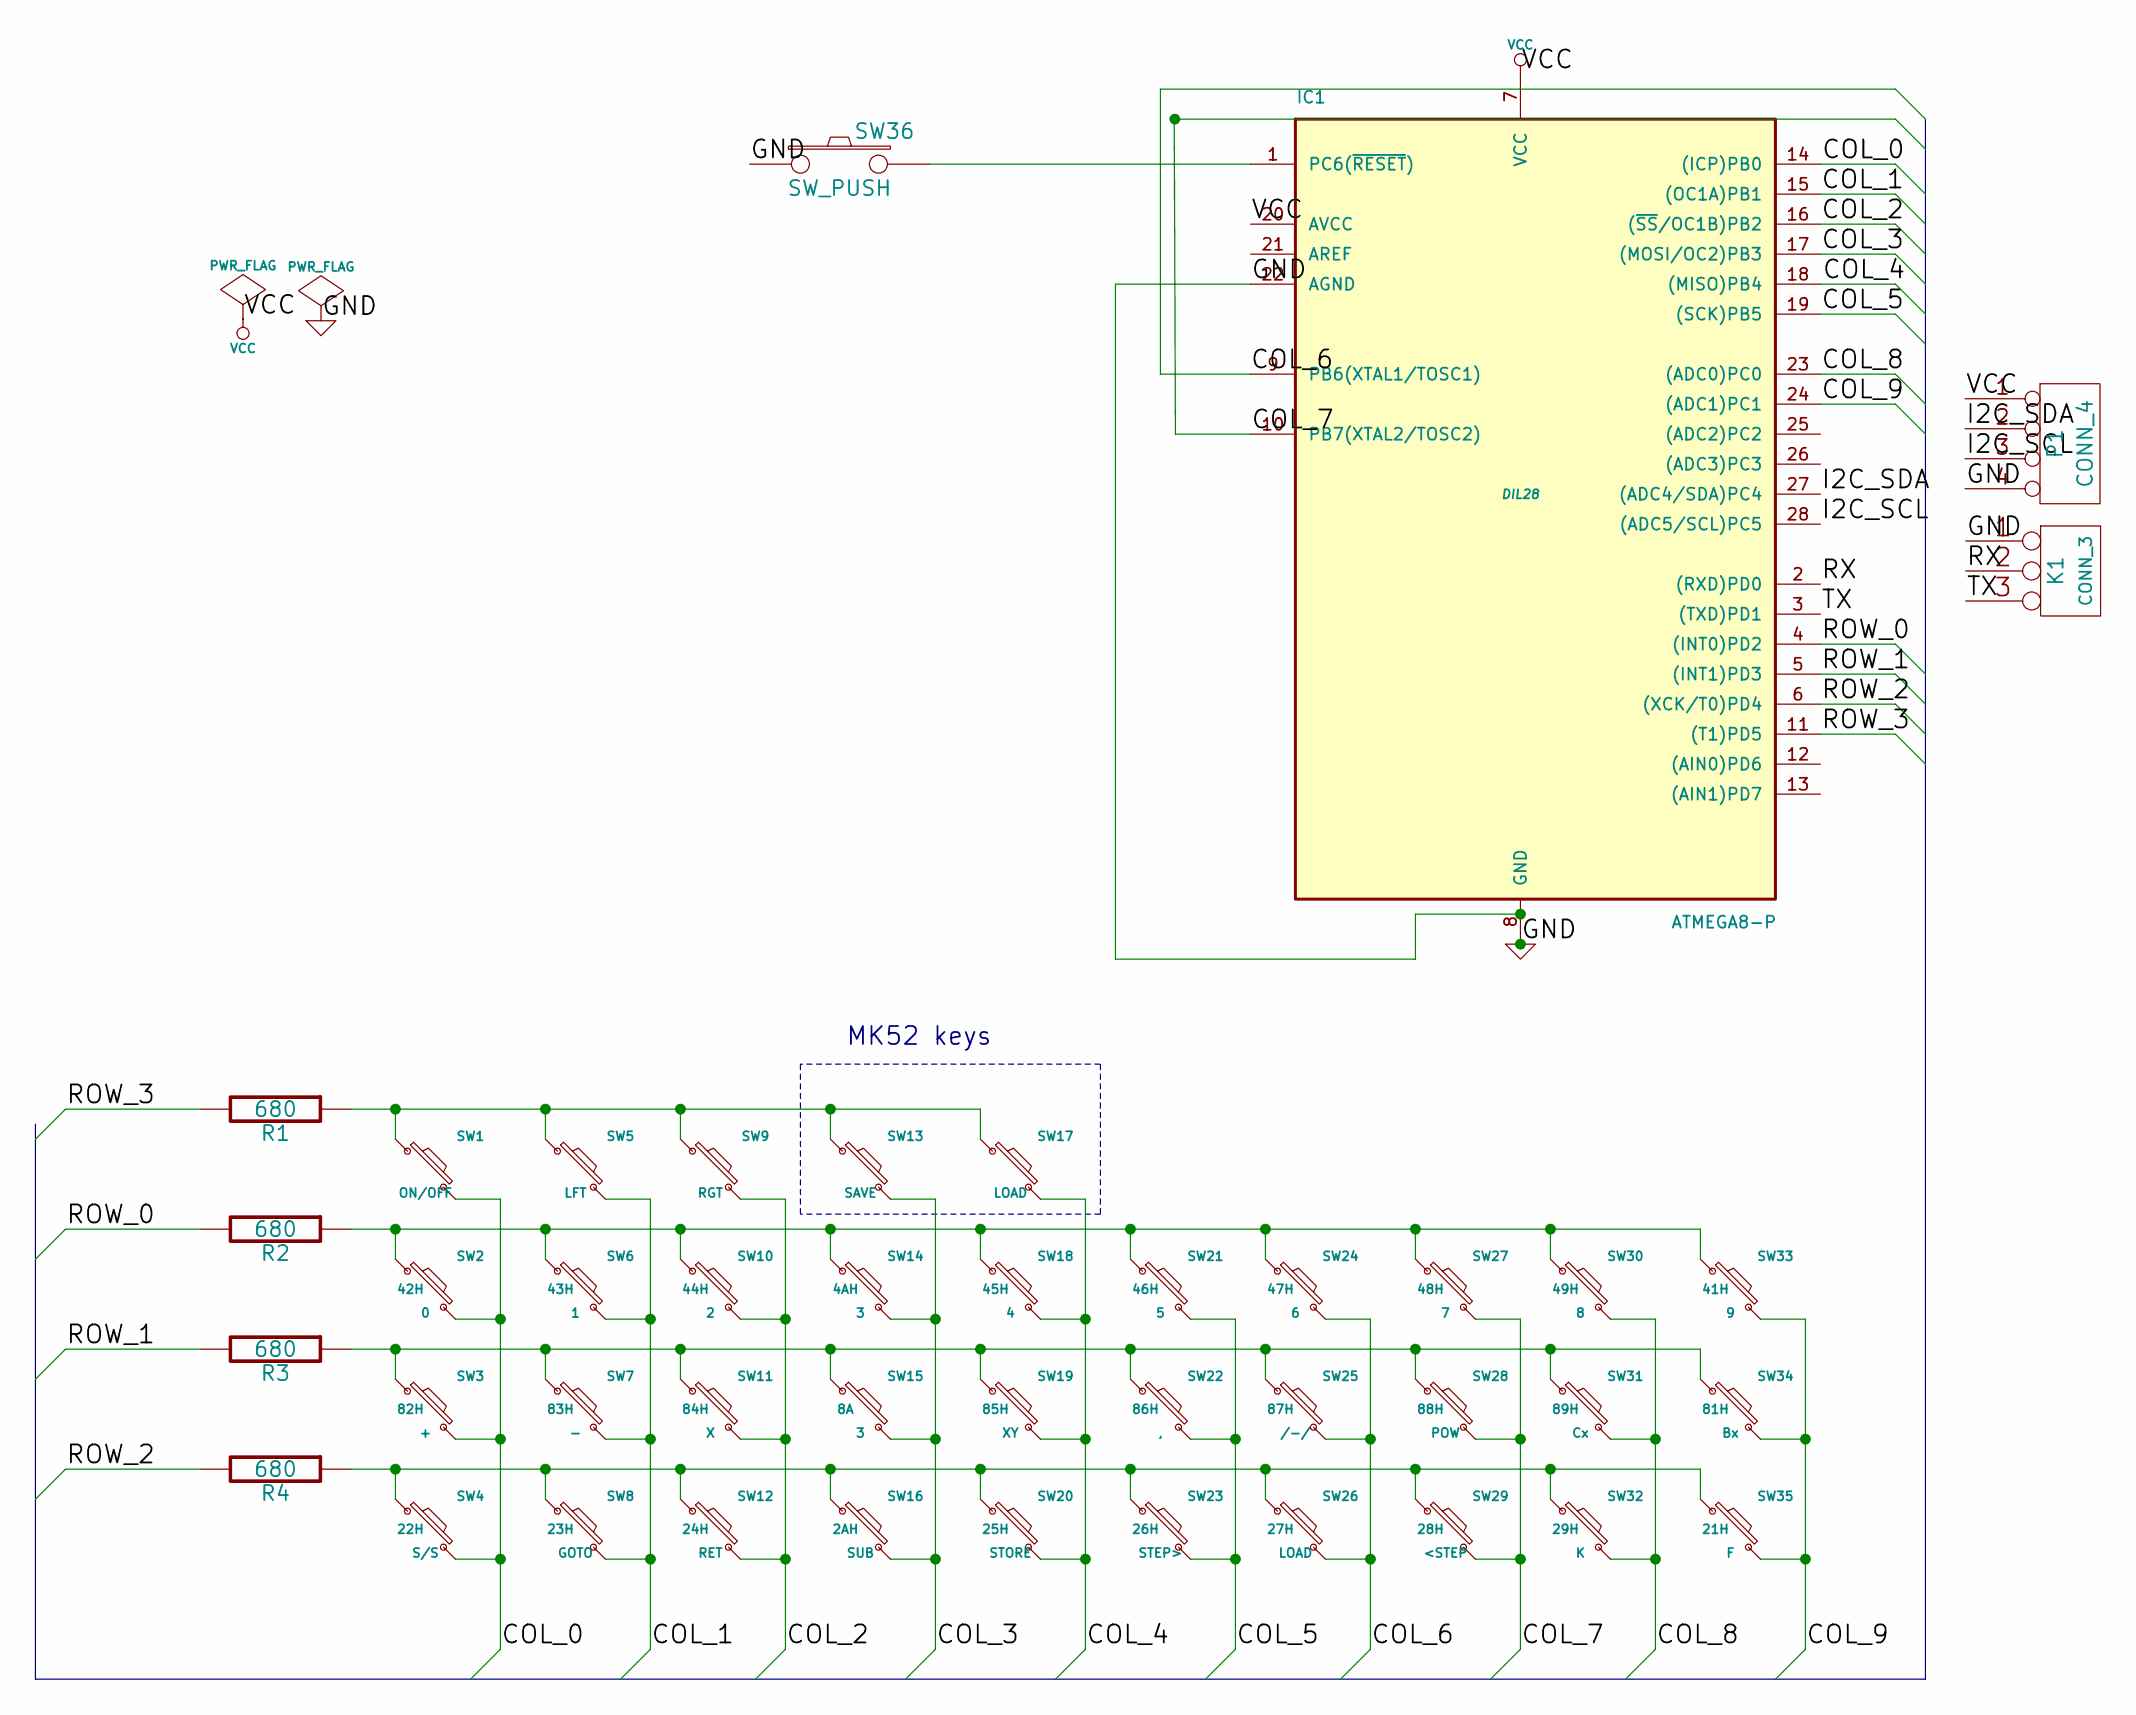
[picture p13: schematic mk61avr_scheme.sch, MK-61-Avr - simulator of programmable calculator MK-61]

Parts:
IC1: ATMEGA8-P; DIL28
K1: CONN_3
P1: CONN_4
R1, R2, R3, R4: 680
SW1: ON/OFF
SW2: 0
SW3: +
SW4: S/S
SW5: LFT
SW6: 1
SW7: -
SW8: GOTO
SW9: RGT
SW10: 2
SW11: X
SW12: RET
SW13: SAVE
SW14, SW15: 3
SW16: SUB
SW17, SW26: LOAD
SW18: 4
SW19: XY
SW20: STORE
SW21: 5
SW22: ,
SW23: STEP>
SW24: 6
SW25: /-/
SW27: 7
SW28: POW
SW29: <STEP
SW30: 8
SW31: Cx
SW32: K
SW33: 9
SW34: Bx
SW35: F
SW36: SW_PUSH

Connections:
/COL_0: IC1.14 ((ICP)PB0), SW1.2, SW2.2, SW3.2, SW4.2
/COL_1: IC1.15 ((OC1A)PB1), SW5.2, SW6.2, SW7.2, SW8.2
/COL_2: IC1.16 ((~SS~/OC1B)PB2), SW9.2, SW10.2, SW11.2, SW12.2
/COL_3: IC1.17 ((MOSI/OC2)PB3), SW13.2, SW14.2, SW15.2, SW16.2
/COL_4: IC1.18 ((MISO)PB4), SW17.2, SW18.2, SW19.2, SW20.2
/COL_5: IC1.19 ((SCK)PB5), SW21.2, SW22.2, SW23.2
/COL_6: IC1.9 (PB6(XTAL1/TOSC1)), SW24.2, SW25.2, SW26.2
/COL_7: IC1.10 (PB7(XTAL2/TOSC2)), SW27.2, SW28.2, SW29.2
/COL_8: IC1.23 ((ADC0)PC0), SW30.2, SW31.2, SW32.2
/COL_9: IC1.24 ((ADC1)PC1), SW33.2, SW34.2, SW35.2
/I2C_SCL: IC1.28 ((ADC5/SCL)PC5), P1.3
/I2C_SDA: IC1.27 ((ADC4/SDA)PC4), P1.2
/ROW_0: IC1.4 ((INT0)PD2), R2.2
/ROW_1: IC1.5 ((INT1)PD3), R3.2
/ROW_2: IC1.6 ((XCK/T0)PD4), R4.2
/ROW_3: IC1.11 ((T1)PD5), R1.2
/RX: IC1.2 ((RXD)PD0), K1.2 (PM)
/TX: IC1.3 ((TXD)PD1), K1.3
GND: IC1.8 (GND), IC1.22 (AGND), K1.1, P1.4, SW36.1
unnamed: R3.1, SW3.1, SW7.1, SW11.1, SW15.1, SW19.1, SW22.1, SW25.1, SW28.1, SW31.1, SW34.1
unnamed: IC1.1 (PC6(~RESET~)), SW36.2
unnamed: R4.1, SW4.1, SW8.1, SW12.1, SW16.1, SW20.1, SW23.1, SW26.1, SW29.1, SW32.1, SW35.1
unnamed: R1.1, SW1.1, SW5.1, SW9.1, SW13.1, SW17.1
unnamed: R2.1, SW2.1, SW6.1, SW10.1, SW14.1, SW18.1, SW21.1, SW24.1, SW27.1, SW30.1, SW33.1
VCC: IC1.7 (VCC), IC1.20 (AVCC), P1.1

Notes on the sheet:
MK52 keys

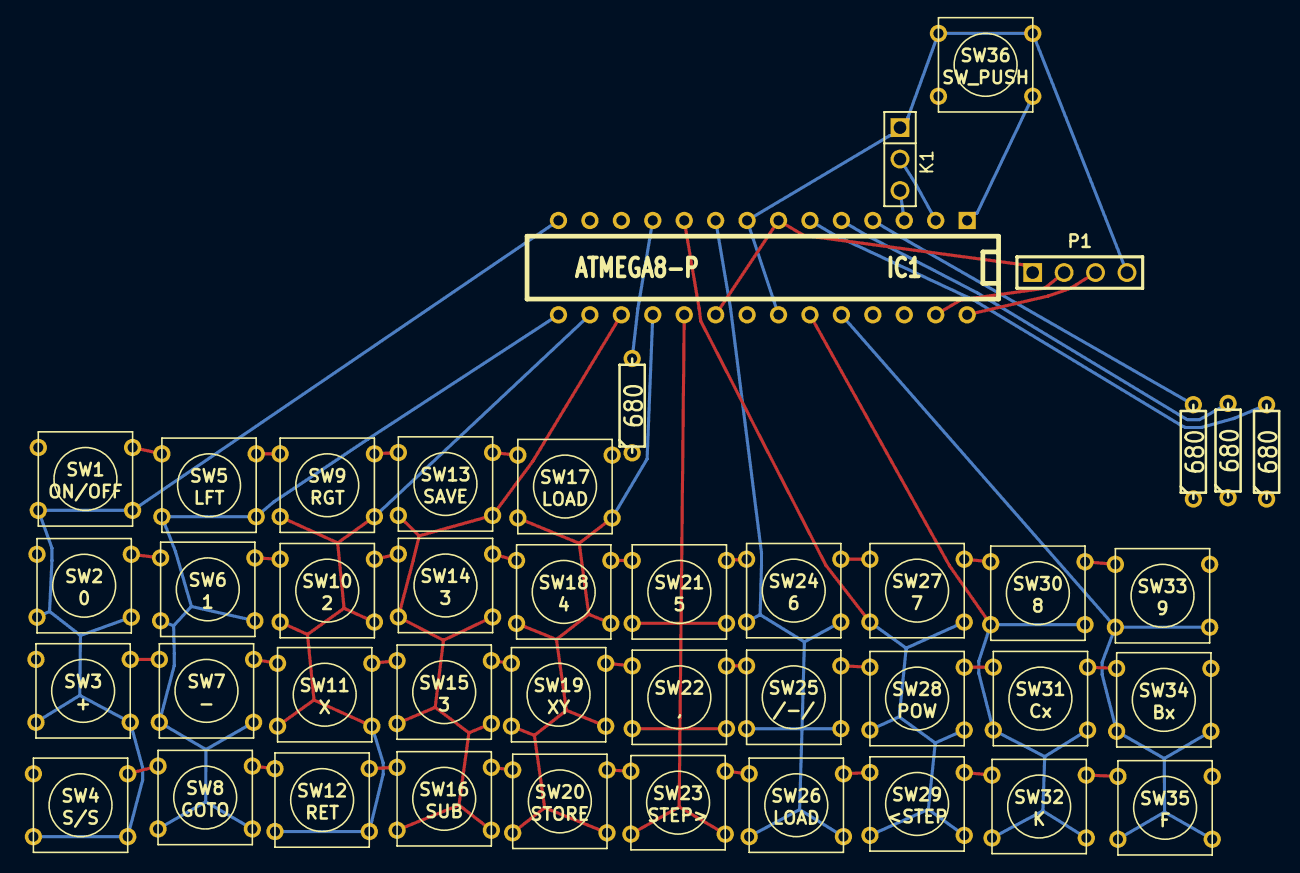
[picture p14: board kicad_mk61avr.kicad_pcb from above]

Board: 2 copper layers, 43 parts (0 on the bottom side), 25 nets.

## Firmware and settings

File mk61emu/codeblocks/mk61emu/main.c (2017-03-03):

/*
 */

#include <avr/io.h>
#include <util/delay.h>
#include <avr/interrupt.h>
#include <stdlib.h>

/*  (c0,c1,c2,c3) + (d2,d3,d4,d5)
     (b0,b1,b2,b3,b4)

#define  NUM_ROWS  8
#define  NUM_COLS  5
byte rowPins[NUM_ROWS] = {A0, A1, A2, A3, 2, 3, 4, 5}; //connect to the row pinouts of the keypad
byte colPins[NUM_COLS] = {8, 9, 10, 11, 12}; //connect to the column pinouts of the keypad

В данном скетче сканирование идет по столбцам, то есть на них подается сигнал, а снимается со строк.
Значит диоды ставятся на пины, подключенные к столбцам, чтобы исключить КЗ между столбцами с выставленным 0 и 1,
а резисторы ограничивают ток на читающих пинах.



                                     D8 D9 D10 D11 D12

                                      |  |  |  |  |
                                      d  d  d  d  d
                                      1  2  3  4  5
                                      |  |  |  |  |
                   +==================+==+==+==+==+====+
          R1 _     |                . |  |  |  |  |    |   _ r8
   A3   ----|_|----+--1--2--3--4--5 . 6--7--8--9--0----+--|_|---   D2
          r2 _     |  |  |  |  |  | . |  |  |  |  |    |   _ r7
   A4   ----|_|----+--Q--W--E--R--T . Y--U--I--O--P----+--|_|---   D3
          r3 _     |  |  |  |  |  | . |  |  |  |  |    |   _ r6
   A5   ----|_|----+--A--S--D--F--G . H--J--K--L--ENTER+--|_|---   D4
          r4 _     |  |  |  |  |  | . |  |  |  |  |    |   _ r5
   A6   ----|_|----+--^--Z--X--C--V . B--N--M--#--' '--+--|_|---   D5
                   +==+==+==+==+==+===+==+==+==+==+====+
                      |  |  |  |  |___|  |  |  |  |
                      |  |  |  |_________|  |  |  |
                      |  |  |_______________|  |  |
                      |  |_____________________|  |
                      |___________________________|
                       ____ ____
                       |   U   |          _______________________
              reset----|1    28|--A5--scl+    LCD 16x2          |
              rx-------|2    27|--A4--sda+______________________|
              tx-------|3    26|-------------------K1-строки
     строки   K2-------|4  a 25|-------------------K1-левой
     левой    K2-------|5  t 24|-------------------K1-половины
     половины K2-------|6  m 23|-------------------K1-клавиатуры
                   vcc-|7  e 22|-gnd
                   gnd-|8  g 21|-
                      -|9  a 20|-vcc
                      -|10 8 19|-
  клавиатуры  K2-------|11   18|---------K3 матрицы
                      -|12   17|---------K3 клавиатуры
                      -|13   16|---------K3
      столбци K3-------|14   15|---------K3
                       |_______|

*/

/*
   пока используем atmega8

команды типа ПП-БП - параметр из двух цифр длина команды 2 байта - код команды и адрес перехода
команды типа X-П - второе нажатие - параметр - номер регистра


   клавиатура на основе mk52
   F   ШГ>  П->X   7   8   9   -   /
   K   ШГ<  X->П   4   5   6   +
   ||  В/О  БП     1   2   3   <-> В|
   А|  С/П  ПП     0   .   /-/ ВП  Cx
*/
#include "scancode_dc.h"
#define MEMSIZE 105
uint8_t mem [MEMSIZE];
uint8_t pp = 0; //указатель програмной памяти (адрес выполняемой команды)
uint8_t mode = 0; //0 - интерактивный режим, 1- выполнение программы, 2 - ввод программы
uint8_t lastCmd; //последняя принятая с клавиатуры команда
uint8_t cmdReady = 0; //признак, что пришла команда с клавиатуры :0=нет


char screenX[16] = " 0              ";
uint8_t scP = 1; // указатель на текущую позицию экранного представления X. 0-разряд знака, 1-первый значащий разряд
char digits[12] = "0123456789.-";
float x = 0;
float y = 0;
float z = 0;
float t = 0;
float x1 = 0;

void writeSerial(char str[])
{
	 int lng=strlen(str);

    for (int i=0; i < lng; i++)    {
        while ( !( UCSRA & (1<<5)) ) {}
        UDR=str[i];
    }
}

void sPush()//втолкнуть значение X в стек c потерей T (стрелка вверх)
{
    t = z;
    z = y;
    y = x;
    x1 = x; // ?
}
void sCycle(float p) // круговое движение стека назад
{
    x1 = x;
    x = y;
    y = z;
    z = t;
    t = x1;
}

void sOp(uint8_t op) // выполнить операцию со стеком
{
    float resOp=0;
    switch (op)
    {
    case op_Add:
        resOp = x + y;
        break;
    case op_Sub:
        resOp = x - y;
        break;
    case op_Mul:
        resOp = x * y;
        break;
    case op_Div:
        resOp = x / y;
        break;
    default:
        resOp=0;

    }
    // спуск стека вниз, съедание регистра Y. X=результат операции
    x1 = x;
    x = resOp;
    y = z;
    z = t;
}

void addDigitToX(uint8_t d)
{
    if (d > 11 ) return; // 0123456789./-/
    else if (d < 11 )
    {
        screenX[scP++] = digits[d];
        screenX[scP] = 0;
    }
    else screenX[0] = '-'; // меняем знак числа в X
    //дальше - синхронизировать X и screenX
    x = atof(screenX);
}

void setup()
{
//USART
   UCSRB|=(1<<3)|(1<<4);
    UBRRH=0x00;
    UBRRL=0x33;

//    Serial.begin(9600);
    DDRB = DDRB | 0b00000001;  // this sets pin8 as output without changing the value of the other pins
    DDRB = 0xFF;  // инициализировать клавиатуру
    PORTB = 0xFF;
    DDRC = 0x00;
    PORTC = 0b00001111; //0x0F;
    DDRD = 0x00;
    PORTD = 0b00111100; //0x0F;
    _delay_ms (10);
    cli();      // Disable interrupts while loading registers
    // Set the registers
    TCCR1A = 0; //Timer Counter Control register
    // Set mode
    TCCR1B = (1 << WGM12); // turn on CTC mode
    // Set prescale values (1024). (Could be done in same statement as setting the WGM12 bit.)
    TCCR1B |= (1 << CS12) | (1 << CS10);
    //Enable timer compare interrupt===> TIMSK1 for ATmega328,
    //TIMSK for ATmega8
    TIMSK |= (1 << OCIE1A);
    // Set OCR1A
    //OCR1A = 15624;
    OCR1A = 4092;
    sei();    // Enable global interrupts

}

#define KEY_ENTER 13
#define KEY_BRK '#'
#define SYMBOL_SHIFT 1
#define CAPS_SHIFT 2


// Keyboard
#define  ROWS  8
#define  COLS  5
char a[ROWS][COLS] =
{
    {'5', '4', '3', '2', '1'},
    {'T', 'R', 'E', 'W', 'Q'},
    {'G', 'F', 'D', 'S', 'A'},
    {'V', 'C', 'X', 'Z', CAPS_SHIFT},
    {'6', '7', '8', '9', '0'},
    {'Y', 'U', 'I', 'O', 'P'},
    {'H', 'J', 'K', 'L', KEY_ENTER},
    {'B', 'N', 'M', SYMBOL_SHIFT, ' '}
};

int i = 0;
int j = 0;
char keyPressed = 0;

void  kb_scan()
{
//  lastCmd=0;
//  mode=0;
//  cmdReady=0;

    for (i = 0; i < COLS; i++)
    {
        PORTB &= ~(1 << i);
        _delay_ms (20);
        for (j = 0; j < ROWS / 2; j++)
        {
            if (!(PINC & (1 << j)))
            {
                keyPressed = a[j][i];
            }
            else if (!(PIND & (1 << (j + 2))))
            {
                keyPressed = a[j + 4][i];
            }
            else if (keyPressed != 0)
            {
//               Serial.println(keyPressed);
                keyPressed = 0;
            }
        }
        PORTB |= (1 << i);
        _delay_ms (10);
    }
}

ISR (TIMER1_COMPA_vect)
{
    //digitalWrite(8, !digitalRead(8));
    //PORTB ^= _BV(PB0); // as digitalWrite(8,x) is an Arduino
    //function, direct writing to the port may be preferable
    kb_scan();
}

uint8_t storeOne(uint8_t op)   // записать в програмную память одну команду программы
{
    if (op<0xff)//заглушка для проверки, что команда подходит для режима программирования
    {
        mem[pp++]=op;
    }
    return 0;
}

uint8_t execOne(uint8_t op)   // выполнить одну команду программы
{
    uint8_t ret=0;
    switch (op)
    {
    case 0x00:
    case 0x01:
    case 0x02:
    case 0x03:
    case 0x04:
    case 0x05:
    case 0x06:
    case 0x07:
    case 0x08:
    case 0x09:
    case 0x0a: // .
    case 0x0b: // /-/
        addDigitToX(op);
        break;
    case 0x0c: // Вп - ввод порядка числа
    {
    }
    break;
    case 0x0d:
        x = 0;
        break;
    case 0x0e:
        sPush();

    default:
    {
//        Serial.println("Unavailable yet!");
        ret=1;
    }
    break;
    }
    return ret;
}

uint8_t runner()   // записать в програмную память одну команду программы
{
    uint8_t ret=0;
    while (pp<MEMSIZE)
    {

        ret=execOne(mem[pp++]);
    }
    return ret;
}

void serialShowStatus()
{
    /*    Serial.println("Stack");
        Serial.println(" T=" + String(t));
        Serial.println(" Z=" + String(z));
        Serial.println(" Y=" + String(y));
        Serial.println(" X=" + String(x));
        Serial.println("x1=" + String(x1));
        Serial.println("screenX=" + String(screenX));
        Serial.println("PROG");
        Serial.println("Mode=" + String(mode));
        Serial.println("->" + String(pp));*/
}

void show()
{
    serialShowStatus();

}
/*
void test()
{
    addDigitToX(1);
    serialShowStatus();
    addDigitToX(2);
    serialShowStatus();
    addDigitToX(3);
    serialShowStatus();
    addDigitToX(4);
    serialShowStatus();
    addDigitToX(10);
    serialShowStatus();
    addDigitToX(6);
    serialShowStatus();
    addDigitToX(11);
    serialShowStatus();
}*/

void loop()  //0 - интерактивный режим, 1- выполнение программы, 2 - ввод программы
{
    uint8_t ret=0;
    writeSerial("test\n");
    if (cmdReady)
    {
        if (mode == 0 ) //интерактивный режим работы
        {
            ret=execOne(lastCmd);
        }
        else if (mode == 2 )
        {
            ret=storeOne(lastCmd);// сохранить команду в памяти
        }
        else if (mode == 3 )
        {
            ret=runner();// сохранить команду в памяти
        }
        show();// отобразить результат
        cmdReady=0;
    }
}


int main(void)
{
    setup();

    while (1)
    {
        loop();
    }

    return 0; // никогда не дойдет сюда
}

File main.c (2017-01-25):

// ***********************************************************
// Project: Эмулятор программируемого калькулятора МК-61 на AVR:
// https://github.com/doleynikov/mk61avr
//
// Copyright (с) 2017 Алексей Сугоняев, Виталий Самуров, Дмитрий Олейников
//
// Module name: main.c
//
// Module description:
//
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
// ***********************************************************
//**********************************************************
//
#include <inttypes.h>
#include <avr/io.h>
#include <avr/interrupt.h>
#include <avr/sleep.h>
#include <avr/eeprom.h>
#include <avr/pgmspace.h>
#include <stdlib.h>
#include <string.h>
#include "config.h"
#include <math.h>
#include "micro_os.h"
#include "mk61types.h"
#include "usart_module.h"
#include "time.h"
//#include "i2c.h"
//#include "store.h"
#ifdef MK61_KEYPAD_IN_USE
 #include "keyboard.h"
 #include "scancode_dc.h"
#endif // #ifdef MK61_KEYPAD_IN_USE
#include "terminal.h"
//#include "lcd.h"
#include "extlib.h"

void InitHAL(void);
void InitVM61(void);
void MK61_CStack_push(void);
void MK61_CStack_pop(void);
void MK61_AStack_push(void);
void MK61_AStack_pop(void);
void ExecRS232Stop(void);
//void OutputLCD_m1(void);
//void OutputLCD_m0(void);
void MK61_displayed(void);

typedef union
{
    long int val;
    char a[4];
} uVector;

double to_R_GR_G(double X);
double from_R_GR_G(double X);

uOS_SIGNALS OS;

register unsigned char PC asm("r2");
register unsigned char OPCODE asm("r3");

// Арифметический стек
register double X asm("r4");
register double Y asm("r8");
register double X1 asm("r12");
double Z,T;


register uALUF ALU61 asm("r16");        // Флаги АЛУ виртуальной машины VM61
//uVM_61_STATE VM61;                    // Флаги управления виртуальной машиной VM61

// Предстоящий переход
register unsigned char TEMP asm("r17");

char disp[16];                 // Буфер для хранениея CHAR эквивалента экрана
char dispprg[12];              // Буфер для формирования дисплея при программировании
char *pPutX = disp;            // Указатель в буфере CHAR эквивалента X на позицию ввода цифры

/*
// Массив маш-кодов (программа) МК61 105 - шагов, свыше резервировано для терминального ввода
unsigned char MK61.prg[256];
// Таблица меток
unsigned int label[256];
// Регистры общего назначения МК61 0..E - РОН
double MK61.reg[16];
// Стек возвратов MK61
unsigned char MK61ret[6];
unsigned char *pCStack = &MK61ret[5];
*/
sMK61 MK61;


shellcall *CmdHook;
unsigned char COMMAND_BUFFER[16];

const char aStepLine[]     PROGMEM = "%x. %x\r";
const char aStopLine[]     PROGMEM = "\rmk61avr [%x. %x]>";
const char aMemStartLine[] PROGMEM = "%x. ";
const char aProgramLine[]  PROGMEM = "%x:%x:%x:%x";
const char aKbdExecEvent[] PROGMEM = "\rrun";

const unsigned char PROGMEM MK61op[16] =
/* *    +    ,    -    .    /    0    1    2    3    4    5    6    7    8    9 */
 {0x12,0x10,0x54,0x11,0x0A,0x13,0x00,0x01,0x02,0x03,0x04,0x05,0x06,0x07,0x08,0x09};


// данные для записи в регистр UCSRA
#define UCS_A (1<<U2X)

// данные для записи в регистр UCSRB
#define UCS_B ((1<<RXEN)|(1<<TXEN)|(1<<UDRIE)|(1<<RXCIE))

// данные для записи в регистр UCSRC
#define UCS_C (1<<URSEL)|(1<<USBS)|(1<<UCSZ1)|(1<<UCSZ0)
#define BOD_2400 416


/*************************************************************************
Name: JMP_TABLE

Input:    none

Returns:  none
*************************************************************************/
void JMP_TABLE(void);


/*************************************************************************
Name: InitHAL

Input:    none

Returns:  none

    Настройка динаимческой индикации дисплея и порта USART
*************************************************************************/
void InitHAL(void)
{
    MCUCR |= (1<<SE);
    asm volatile(
    "push r28"                  "\n\t"
    "ldi r28, 0x02"             "\n\t"      // Линия TX на вывод, линия RX на ввод, остальные на ввод
    "out %[ddrd], r28"          "\n\t"
    "ldi r28, 0xFF"             "\n\t"
    "out %[portd], r28"         "\n\t"      // все линии подтянуть к VCC

#ifdef MK61_KEYPAD_IN_USE
    "clr r28"                   "\n\t"
    "out %[ddrc], r28"          "\n\t"      // все линии порта C на ввод
    "out %[ddra], r28"          "\n\t"      // все линии порта A на ввод
    "out %[ddrb], r28"          "\n\t"      // все линии порта B на ввод
    "ser r28"                   "\n\t"
    "out %[portc], r28"         "\n\t"      // все линии порта C подятнуть к VCC
    "out %[porta], r28"         "\n\t"      // все линии порта А подятнуть к VCC
    "out %[portb], r28"         "\n\t"      // все линии порта B подятнуть к VCC
#endif // #ifdef MK61_KEYPAD_IN_USE

    "ldi r28, hi8(416)"         "\n\t"      // hi baud rate
    "out %[ubrrh], r28"         "\n\t"
    "ldi r28, lo8(416)"         "\n\t"      // lo baud rate
    "out %[ubrrl], r28"         "\n\t"
    "ldi r28, %[ucs_A]"         "\n\t"
    "out %[ucsra], r28"         "\n\t"
    "ldi r28, %[ucs_B]"         "\n\t"
    "out %[ucsrb], r28"         "\n\t"
    "ldi r28, %[ucs_C]"         "\n\t"      // URSEL, USBS, UCSZ1, UCSZ0 2 stop bit,
    "out %[ucsrc], r28"         "\n\t"
#ifdef RC_OSC_CALIBRATE
    "ldi r28, %[oscval]"        "\n\t"
    "out %[osccal], r28"        "\n\t"
#endif // #ifdef RC_OSC_CALIBRATE
    "pop r28"                   "\n\t"
    :
    : [ddrb] "I" (_SFR_IO_ADDR(DDRB)),
      [ddrd] "I" (_SFR_IO_ADDR(DDRD)),
      [ddrc] "I" (_SFR_IO_ADDR(DDRC)),
//      [ddra] "I" (_SFR_IO_ADDR(DDRA)),
      [portb] "I" (_SFR_IO_ADDR(PORTB)),
      [portd] "I" (_SFR_IO_ADDR(PORTD)),
      [portc] "I" (_SFR_IO_ADDR(PORTC)),
//      [porta] "I" (_SFR_IO_ADDR(PORTA)),
      [ubrrh] "I" (_SFR_IO_ADDR(UBRRH)),
      [ubrrl] "I" (_SFR_IO_ADDR(UBRRL)),
      [ucsra] "I" (_SFR_IO_ADDR(UCSRA)),
      [ucsrb] "I" (_SFR_IO_ADDR(UCSRB)),
      [ucsrc] "I" (_SFR_IO_ADDR(UCSRC)),
      [osccal] "I" (_SFR_IO_ADDR(OSCCAL)),
      [oscval] "M" (0xB0),                  //B0
      [ucs_A] "M" (UCS_A),
      [ucs_B] "M" (UCS_B),
      [ucs_C] "M" (UCS_C)
    );

    pBuff_UART   = 0;
    OS.VAL   = 0;
    dump[49] = 0x00;

    // Инициализация задатчика времени OS и шедуллера событий по времени
    TIME_Init();

    // Инициализация модуля TWI (I2C)
//    TWI_Init();
//    STORE_init();

    // Init lcd
//    lcd44780_init(LCD_DISP_ON);

    // Clear display and home cursor
//    lcd44780_clrscr();

#ifdef MK61_KEYPAD_IN_USE
    Keyboard_Init();
    ScanDC_RESET();
#endif

    // Настройка "сна"
#ifdef __AVR_ATmega8__
    MCUCR |= (1<<SE)|(0<<SM2)|(0<<SM1)|(0<<SM0);       // standby for sleep
#endif

#ifdef __AVR_ATmega16__
    MCUCR  |= (1<<SE)|(0<<SM2)|(0<<SM1)|(0<<SM0);
    // EMCUCR |= (0<<SM0);
#endif
}


/*************************************************************************
Name: InitVM61

Input:    none
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

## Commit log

2017-01-16 latest fzz
    [mk61avr.fzz]
2017-01-16 Recover FZZ
    [mk61avr.fzz]
2017-01-16 FZZ: USBASP added
    [mk61avr.fzz]
2017-01-16 FZZ: I2C and UART added
    [mk61avr_I2C.fzz]
2017-01-16 FZZ: updated
    [mk61avr_I2C.fzz]
2017-01-17 KiCAD:added schematic
    [mk61avr_scheme.sch]
2017-01-17 KiCAD:some editing
    [mk61avr_scheme.sch]
2017-01-18 KiCAD:PCB design from TopoR
    [kicad_mk61avr.dsn, kicad_mk61avr.kicad_pcb]
2017-01-18 Подправлены комментарии и изменен readme для github
2017-01-18 USBASP plug added to schematics
    [mk61avr_scheme.sch]
2017-01-19 KiCAD: обновил схему от Алексея
    [mk61avr_scheme.sch]
2017-01-20 Обновил README
2017-01-24 KICAD: переделал схему клавиатуры под матрицу 5x8
    [mk61avr_scheme.sch]
2017-01-25 пилил исходники
2017-01-25 пилил исходники1
2017-01-31 схема
    [mk61avr_scheme.sch]
2017-01-31 KICAD: arduino added
    [mk61avr_scheme.sch]
2017-02-02 KiCAD: PDF added
2017-02-08 эксперимент с драйвером клавиатуры по таймеру - разобраться с повторными нажатиями
2017-02-10 эксперименты
2017-02-14 bit-op : some corrections
    [bit_ops.ino]
2017-03-01 чистка репозитория
2017-03-01 небольшие исправления
2017-03-02 п÷я─п╬п╠я┐я▌ п╢п╬п©п╦я│п╟я┌я▄ я│п╡п╬п╧ я█п╪п╦я┌п╟я┌п╬я─
2017-03-02 п╢п╬я─п╟п╠п╬я┌п╨п╦
2017-03-03 п©я─п╬п╢п╬п╩п╤п╣п╫п╦п╣
2017-03-27 п▓я─п╬п╢п╣ я─п╟п╠п╬я┌п╟п╣я┌ п╨п╩п╟п╡п╦п╟я┌я┐я─п╟
2017-03-30 SPI-SRAM test added (avr-gcc Makefile)
2017-04-02 avrgcc version of i2c LCD test added
2017-04-02 LCD pins are corrected
    [lcdpcf8574.h]

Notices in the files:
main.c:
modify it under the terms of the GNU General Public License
